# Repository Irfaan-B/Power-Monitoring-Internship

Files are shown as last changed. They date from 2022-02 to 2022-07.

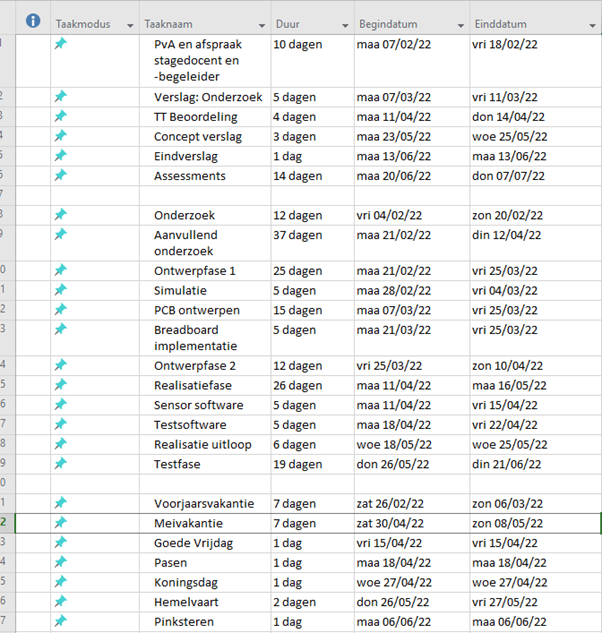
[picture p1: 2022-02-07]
Plan van Aanpak/Planning1.png

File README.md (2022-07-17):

# Three-Phase Power Monitor
A repository meant as version control for my internship at Crownstone.

## Plan of Action
The plan of action for this project can be found [here](https://github.com/IrfaanBodha/Power-Monitoring-Internship/blob/main/Research/Research.pdf)

A planning made for the second half of the project can be found [here](https://github.com/IrfaanBodha/Power-Monitoring-Internship/blob/main/Plan%20van%20Aanpak/Internship%20Planning%20(Second%20half).pdf)

## Report
Here you can find documents describing the research that has been done for this project:

- [Research on sensors](https://github.com/IrfaanBodha/Power-Monitoring-Internship/blob/main/Research/Research.pdf)
- [Test PCB for Rogowski coils and TMR sensors]
   - [Simulations](https://github.com/IrfaanBodha/Power-Monitoring-Internship/blob/main/Test%20Board/Simulations.pdf)
   - [Explanation of the schematic](https://github.com/IrfaanBodha/Power-Monitoring-Internship/blob/main/Test%20Board/Test%20board%20Explanation.pdf)
   - [Altium project files](https://github.com/IrfaanBodha/Power-Monitoring-Internship/tree/main/Test%20Board)

## The Product
This section will contain links leading to various files associated with the product that is being developed.

- [Internship Report](Report/Internship_Report.pdf)
- [Schematic](TPPM/TMRSensors.SchDoc)
- [Explanation of the schematic](TPPM/Circuit_Explanation.pdf)
- [PCB Files](TPPM)

## Sources
Sources will be listed in the [internship report](https://github.com/IrfaanBodha/Power-Monitoring-Internship/tree/main/Report).

## License
A file containing the license can be found [here](LICENSE.md)

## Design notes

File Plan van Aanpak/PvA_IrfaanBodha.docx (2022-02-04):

© 2022 Hogeschool Rotterdam

# Power Monitoring

# Plan van Aanpak

Opgesteld door | : | Irfaan Bodha
Stagiair | : | Irfaan Bodha
Begeleiders (Hogeschool Rotterdam) | : | John Roeloffs Robert Inpijn
Begeleider | : | A.C. van Rossum
Datum van uitgifte | : | xx-02-2022

Inhoudsopgave

Versiehistorie

Versie | Datum | Wijzingen | Auteur
0.1 | 03-02-22 | Eerste opzet | I.Bodha
0.11 | 04-02-22 | Risicoanalyse toegevoegd. | I Bodha

# 1. Achtergronden

Crownstone is een bedrijf dat gevestigd is in Rotterdam en is fabrikant van slimme stekkers en connectoren. Een Crownstone (kroonsteentje) product is een 16A schakelaar, LED-dimmer, vermogensmeter, soft-fuse, standby-killer en aanwezigheidssensor ineen. Het unieke kenmerk van dit product is de positiebepaling van smartphones en wearables, dit maakt het mogelijk om automatisch te reageren op aanwezigheid, binnenkomst en vertrek van specifieke personen.

Crownstone werkt aan het slimmer maken van huizen en kantoren. Crownstone gelooft dat huizen en kantoren nooit echt slim zullen worden als ze niet weten waar wij ons bevinden. Ook verwacht Crownstone dat in de toekomst positiebepaling binnenshuis groter zal zijn dan buitenshuis (GPS).

Op dit moment zijn crownstones producten die achter een stopcontact geïnstalleerd kunnen worden om het stopcontact slim te maken. Uiteindelijk wilt Crownstone de stopcontacten zelf slim maken en dus het huidige product integreren met stopcontacten. Slimme stopcontacten met functies als positiebepaling zullen uiteindelijk voor meer comfort, veiligheid en energiebesparing zorgen. Elektronica kan automatisch uitgeschakeld worden bij vertrek van personen wat niet alleen fijn is voor de gebruiker, maar ook energiezuinig. Ook is het veilig, omdat bepaalde elektronica die gevaarlijk zijn voor bijvoorbeeld kinderen, zoals een strijkijzer, automatisch uitgeschakeld zullen worden.

# 2. Projectresultaat

In dit hoofdstuk zal het projectresultaat besproken worden. Als eerst wordt de probleemstelling besproken, waar uitgelegd zal worden waarom dit project gedaan wordt. Vervolgens zal er worden besproken wat het doel van dit project is en welk elektrotechnisch systeem gerealiseerd zal worden in dit project.

## Probleemstelling

Crownstone wilt een product voor het meten van hoge vermogens en 3 fasen, waarbij er geen aanpassing aan de installatie nodig is. Dit is belangrijk voor bijvoorbeeld liften en apparaten in ziekenhuizen, waar het onacceptabel is om bijvoorbeeld een kabel door te knippen om zo individueel te stromen te meten door elke fase.

Op dit moment bestaan er stroomtangen die door middel van het meten van het magnetisch veld de stroom kunnen bepalen dat door een single core draad loopt. Dit is echter niet mogelijk in 3-fasen draden, omdat de netto stroom dat gemeten zal worden 0 zal zijn.

Door middel van het nauwkeurig plaatsen van sensoren zal het echter wel mogelijk zijn om met het nieuw product de stroom door de 3 fasen te meten zonder de kabel door te knippen. Met behulp van magnetische sensoren zal het bijvoorbeeld ook mogelijk zijn om meer te meten dan alleen vermogen, bijvoorbeeld het wegvallen van een fase of de aanwezigheid van triplen harmonics.

## Doelstelling

Het doel van dit project is om uiteindelijk een product te ontwerpen en realiseren dat de vermogen kan meten van een 3-fasen draad zonder dat het apparaat in-line wordt aangesloten. Dit zal gedaan worden met behulp van magnetische sensoren.

Er zal een PCB ontworpen worden die de bovengenoemde sensoren zal bevatten. Ook zal de PCB een microcontroller bevatten, de nRF52832 of de nRF52840. Dit zal nodig zijn om de data van de sensoren uit te kunnen lezen en verwerken.

Tijdens dit project zal er ook software geschreven worden voor de microcontroller. De software zal de data van de sensoren uitlezen en er zal ook testsoftware geschreven worden om de PCB te kunnen testen.

# 3. Projectactiviteiten

Om dit systeem uiteindelijk te kunnen realiseren zullen er specifieke activiteiten plaats moeten vinden. De student zal beginnen met het opstellen van dit plan van aanpak. Vervolgens zal er een analyse uitgevoerd moeten worden om zo de technische en niet-technische eisen te bepalen. De eisen zullen besproken worden met de begeleider.

Vervolgens zal er een onderzoek gehouden worden. Het doel van dit onderzoek is het bestuderen van benodigde theorie die relevant is voor de opdracht, zoals magnetische velden en 3-fasen theorie. Ook zal er tijdens de onderzoek gezocht worden naar geschikte type sensoren.

Het product zal uiteindelijk ontworpen worden in Altium. In dit programma zal dus de PCB ontworpen worden. Ook zal er een PCB gerealiseerd worden.

De schakeling zal ook opgebouwd worden op een breadboard om zo het ontwerp te testen.

Er zal software geschreven worden om de sensoren uit te kunnen lezen, en software om de PCB te testen.

Na het fabriceren van de prototype PCB zal er feedback ontvangen en verwerkt worden, en zullen gemaakte fouten verbeterd worden voor een volgende iteratie. Ook zal de BOM (bill of materials) geoptimaliseerd worden.

# 4. Projectgrenzen

Binnen de scope van deze opdracht valt het schrijven van software om sensoren uit te lezen en testsoftware voor de PCB. Er zal geen software geschreven worden voor het verwerken van de data.

Als er genoeg tijd is zal er ook een ‘pro’ versie van het product ontwikkeld worden. Deze versie zal nauwkeuriger zijn en zal geschikt zijn voor lagere minimum input en hogere maximum input waarden. Deze versie is geen vereiste, maar er zal wel geprobeerd worden om deze versie te realiseren.

De deadline van het verslag voor dit project is 13 juni 2022. Als er eventueel een herkansing nodig is zal het project langer duren.

Een aantal randvoorwaarden om dit project goed af te kunnen ronden zijn:

- Begeleiders moeten beschikbaar zijn voor het leveren van feedback en beantwoorden van vragen.
- De student moet toegang hebben tot een communicatiemiddel om communicatie tussen de student en collega’s mogelijk te maken wanneer er thuis gewerkt wordt, in dit geval een Discord server.
- De student moet toegang krijgen tot een Altium licentie, aangezien het gebruiken van dit programma verplicht is tijdens dit project.
- De student moet toegang krijgen tot faciliteiten om het ontwerp en gerealiseerde PCB’s te kunnen testen.

# 5. Tussenresultaten

- Programma van Eisen
- Het hoofdstuk ‘Onderzoek’
- Een tussentijdse beoordeling van de bedrijfsbegeleider
- Een concept verslag
- Het eindverslag
- Een prototype van het product gebouwd op een breadboard
- Een prototype PCB van het product
- Revisies van de PCB met verwerkte feedback en verbeteringen
- Software om data van sensoren mee uit te lezen
- Testsoftware voor de PCB

# 6. Kwaliteit

Om er zeker van te zijn dat de kwaliteit van dit project voldoet aan de eisen van de opdrachtgever zullen er requirements opgesteld worden. Door het eindproduct met de requirements te vergelijken en te testen zal er zo bepaald worden of de kwaliteit van het product voldoet.

De student zal aan het einde van elke week een email sturen naar de bedrijfsbegeleider om de voortgang toe te lichten. Ook is dit een moment om vragen te stellen en eventuele knelpunten toe te lichten. De student zal ook feedback ontvangen op het ontwerp, de documentatie en het stageverslag. Deze feedback zal dan verwerkt worden waardoor het eindproduct en eindverslag aan de opgestelde eisen zal voldoen.

Voor versiebeheer zal er gebruik worden gemaakt van een publieke Git repository. Met behulp van Git zullen de documenten altijd online beschikbaar zijn voor de begeleiders. Hier (https://github.com/IrfaanBodha/Power-Monitoring-Internship) is een link naar de repository. Als er eventueel documenten zijn die liever privé bewaard worden dan zal er gebruik gemaakt worden van Google Drive.

Voor het ontwerpen van de PCB zal er gebruik gemaakt worden van Altium. Er zal gecommuniceerd worden via Discord. Tot slot zal tekst geschreven worden in LaTeX, op de website van Overleaf.

# 7. Projectorganisatie

Naam | Functie | E-mail
Irfaan Bodha | Stagiair | 0882953@hr.nl irfaan.bodha@gmail.com
Anne van Rossum | Bedrijfsbegeleider | anne@crownstone.rocks
John Roeloffs | Begeleider | j.w.roeloffs@hr.nl
Robert Inpijn | Begeleider | inprm@hr.nl

# 8. Planning

Hier is een overzicht van de planning.

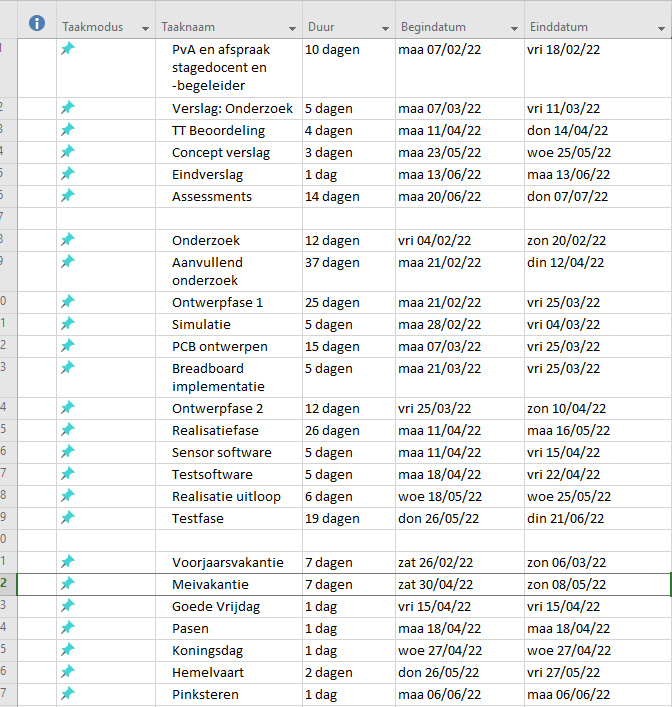
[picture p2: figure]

Voor een strokenplanning zie bijlage [1].

# 9. Kosten en baten

Het totale budget voor het product zal tussen de 300 en 400 euro liggen. Het exacte bedrag is nog niet bekend.

Er zullen 840 uur gespendeerd worden aan het project, waarvan 80 uur aan het stageverslag gewerkt zal worden.

Uiteindelijk zal Crownstone dankzij dit project hun productlijn rondom power monitoring verder uit kunnen breiden. Omdat de bestaande installaties waar de stroom gemeten zal worden niet aangepast hoeven te worden zal dit product zeer handig zijn voor toepassingen waar het aanpassen van de installatie onacceptabel is. Denk hierbij aan bijvoorbeeld het monitoren van een lift of apparaten in een ziekenhuis.

De student zal met behulp van dit project zijn competenties kunnen ontwikkelen en professionele werkervaring opdoen.

# 10. Risico's

Wat kan de voortgang van het project in gevaar brengen?

In dit hoofdstuk zullen de risico’s besproken worden die mogelijk invloed kunnen hebben op het project. Via een risicoanalyse zullen de grootte van de risico’s en mogelijke oplossingen bekend worden.

Een risico is opgebouwd uit de kans van optreden van de gebeurtenis en het gevolg die de gebeurtenis heeft. Kans en Gevolg zullen getallen zijn van 1 tot en met 10, en het risico zal uiteindelijk een vermenigvuldiging zijn van die twee getallen.

Grootte risico = Kans * Gevolg

Risico’s | Kans | Gevolg | Risico | Maatregelen
Onjuiste planning | 3 | 8 | 24 | Preventief: Planning zal gecontroleerd worden door begeleiders, en feedback zal toegepast worden.
Planning is te optimistisch | 5 | 8 | 40 | Preventief: Planning zal gecontroleerd worden door begeleiders, en feedback zal toegepast worden.
Planning wordt niet bijgehouden | 6 | 4 | 32 | Repressief: Zoveel mogelijk proberen om de planning bij te houden.
Te laat beginnen met een activiteit | 7 | 8 | 56 | Preventief: Planning goed bijhouden en zo goed mogelijk proberen te volgen.
Student heeft onvoldoende ervaring | 8 | 1 | 10 | Preventief: Door onderzoek te doen en vragen te stellen zal de benodigde ervaring verkregen worden.
Het project wordt tegengewerkt | 2 | 5 | 10 | Acceptatie.
Student wilt het product ‘te mooi’ maken | 3 | 7 | 21 | Repressief: Door het volgen van de planning zal er niet meer tijd besteed worden aan een onderdeel dan nodig is.
Te late levering van ingekocht materiaal | 8 | 10 | 80 | Preventief: Bestellen bij betrouwbare leveranciers en de levertijden goed controleren.
Vergeten van voorbereidingen | 1 | 10 | 10 | Preventief: Met het opstellen van een plan van aanpak zal de student goed voorbereid zijn.
Calamiteiten | 1 | 10 | 10 | Acceptatie.
Nieuwe overheidsregels | 8 | 8 | 64 | Acceptatie.
Projectopdracht is onduidelijk | 2 | 10 | 20 | Preventief: Door het opstellen van een duidelijk programma van eisen zal dit geen probleem zijn.
Opdracht wijzigt tijdens het project | 1 | 7 | 7 | Repressief: De opdracht en stageovereenkomst zijn geüpload op Praktijklink.
Hoeveelheid werk is moeilijk in te schatten | 6 | 8 | 48 | Preventief: Planning zal gecontroleerd worden door begeleiders, en feedback zal toegepast worden.
Doorlooptijd is onderschat | 1 | 8 | 8 | Preventief: De deadlines en overige data zijn vastgesteld in de planning.
Er is geen rekening gehouden met tegenvallers | 4 | 8 | 32 | Preventief: In de planning zal rekening gehouden worden met eventuele vertragingen.
Einddatum is niet realistisch | 3 | 10 | 30 | Preventief: De opdracht is goedgekeurd door de stagecommissie, dus het zou in principe mogelijk moeten zijn om op tijd af te ronden.
Prijswijzigingen van materialen | 8 | 5 | 40 | Repressief: In het geval dat de wijzigingen te extreem zijn zal er gekeken moeten worden naar andere leveranciers.
Beschikbaarheid producten | 8 | 8 | 64 | Repressief: In het geval dat de gekozen producten niet goed beschikbaar zijn, zal er gekeken moeten worden naar alternatieve leveranciers of producten.
Onbetrouwbare leveranciers | 2 | 8 | 16 | Preventief: Er zal alleen besteld worden van leveranciers waarvan het bekend is dat ze betrouwbaar zijn.
Ziekte | 10 | 7 | 70 | Acceptatie.
Familieproblemen | 5 | 10 | 50 | Acceptatie.
Slechte prestaties/motivatie/houding | 5 | 10 | 50 | Repressief: In het geval dat de student slecht presteert zal dit via meetings met begeleiders verholpen worden.

# Bijlagen

## Bijlage 1

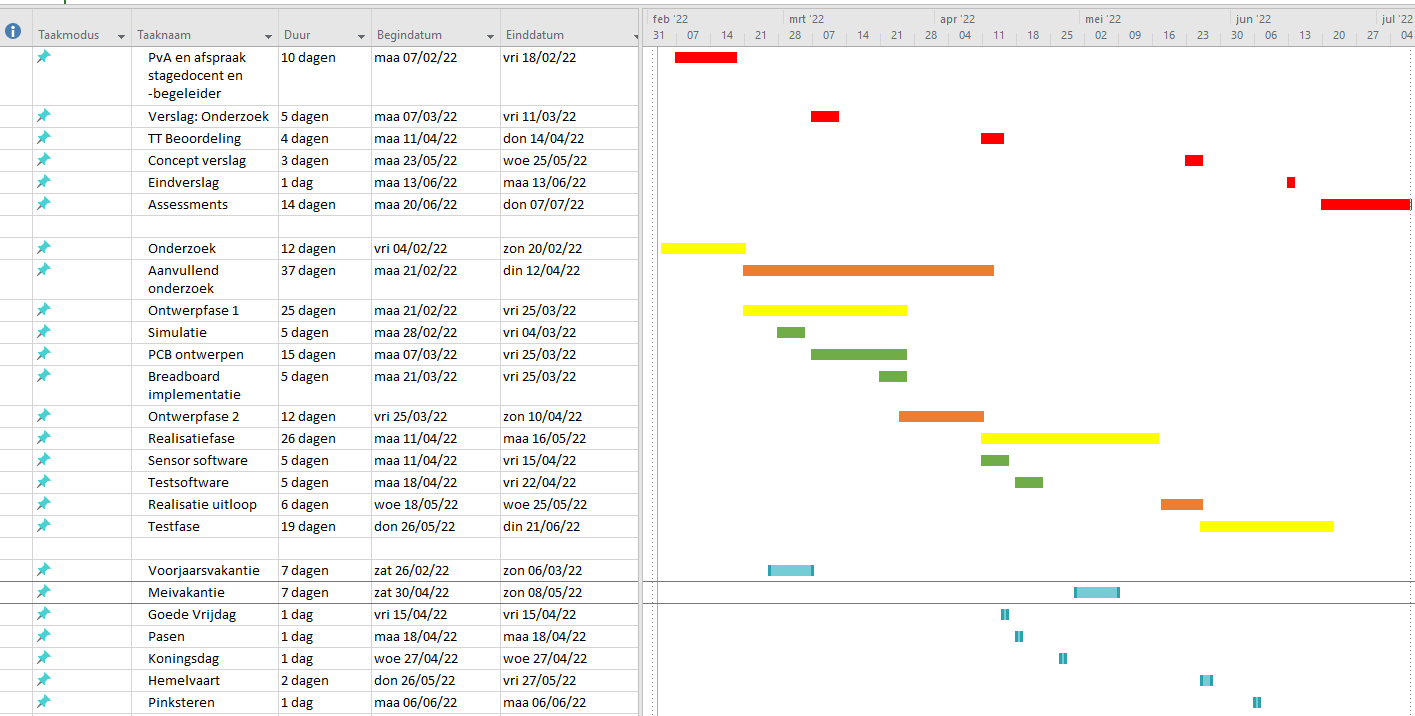
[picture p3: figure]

Versie 0.1Pagina 4 van 4

PvA Power MonitoringHogeschool Rotterdam

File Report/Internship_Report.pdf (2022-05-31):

# Three-Phase Power Monitoring

# Internship Report

## Intern: Irfaan Bodha Company Supervisor: Anne van Rossum Supervisor: John Roeloffs Supervisor: Robert Inpijn

Internship Report | Crownstone

## 1 Summary

This document will walk the reader through the design process of a Three-Phase Power Meter. The necessary research that has been done in order to design the product will be documented. Furthermore, this document shall feature information about the design and integration of the several units that together make up the power meter. A PCB shall be designed for this project, which will also be documented in this report, together with the various performed tests.

## Contents

1 Summary | 1
2 Three-Phase Power Monitor | 4
3 Research | 5
4 System Analysis | 15
5 Architecture | 20
6 Design | 25

7 Test Results | 36

## 2 Three-Phase Power Monitor

### 2.1 Introduction

### 2.1.1 Problem Definition

Crownstone is developing a product that can measure currents running through a three-phase cable in a non-intrusive manner. This will be useful for applications such as an elevator or in a hospital. Not having to interrupt the circuit in order to carry out a current measurement is crucial for these applications.

There are a number of non-intrusive current measurement devices on the market already, however these do not function well for a three-phase cable. The reason for this being the fact that with those devices, the user would be measuring the current on all three phases at once.

### 2.1.2 Aim of This Project

The aim of this project is to design and realise a product that is capable of measuring the current per phase in a three-phase installation in a non-intrusive manner. This device shall also feature the nRF52832 or nRF52840 micro controller, in order to output the data over Bluetooth.

At the end of the project, a PCB shall be designed and realised and the necessary software to read the sensors shall be written.

## 3 Research

This research document shall detail the research and experiments that shall be done in support of the three phase power monitoring project. In order to determine suitable requirements, experiments shall be done on magnetic sensors. The chosen sensors for these experiments are:
- Rogowski Coils
- Hall Effect Sensors
- Magnetoresistive Sensors

An amplifier circuit shall be designed and produced for the Rogowski coil. The procedures and calculations will be detailed in this report. To test the hall effect sensor, a hall effect module shall be connected to an Arduino Uno and the outputs will be read through a PC running an Arduino serial monitor. The magnetoresistive sensors will be mounted to a PCB and will also be read through a PC and Arduino software.

### 3.1 Rogowski Coils

### 3.1.1 Theory

Rogowski coils have been used for current measuring since 1912. [1] Traditionally, Rogowski coils have only been considered when other methods were unsuitable. Starting in 1965, the CEGB laboratories at Harrogate began investigating Rogowski coils for use in the power industry and developed the technology to produce high-accuracy and reliable measuring systems using Rogowski coils. [2]

Rogowski coils are toroidal windings placed around the conductor from which they will be measuring the current of. This way, the coil will pick up the electromagnetic field (EMF). The output of the winding is an EMF proportional to the rate of change of current. This is where the Rogowski coil differs from a current transformer, as a current transformer outputs the current that is being measured. The coils are designed to reject external magnetic fields, so that they may provide accurate measurements. The coil can be wound on a rigid former or it can be wound on a flexible former.

In order to monitor the current, the output of the Rogowski Coil has to be integrated. This is because the output of the coil is proportional to the rate of change of current. For this experiment, however, this shall not be necessary, since we are only interested in how sensitive a Rogowski coil is.

The output of a Rogowski coil is very low however, it can be as low as 40 microvolts per amp. [1] For this reason, an amplifier must be used in order to produce a reliable signal.

By choosing correct values for the amplifier, a single coil could theoretically be used to measure an extremely wide range of currents. The coil itself could also be wound more tightly, in order to increase the number of turns and therefore increasing its sensitivity.

One of the advantageous features of the Rogowski coil is that it is linear, because of this the coil could be used to measure a wide range of currents. Instead of having to change the coil when switching systems, the gain of the amplifier could be adjusted instead.

### 3.1.2 TL074 Amplifier

Two proposed circuits will be discussed in this section. The goal of the circuits shall be to amplify the output of the Rogowski coil so that it may be interpreted by a micro controller or observed through an oscilloscope. The output of the Rogowski coils are extremely low, that’s why the signal must be amplified. An op amp amplifier circuit shall be utilized for this. See figure 1 for a schematic of the amplifier using the TL074 op amp. The gain can be tuned by adjusting the value of R4. We can calculate the gain using this simple formula. 1.

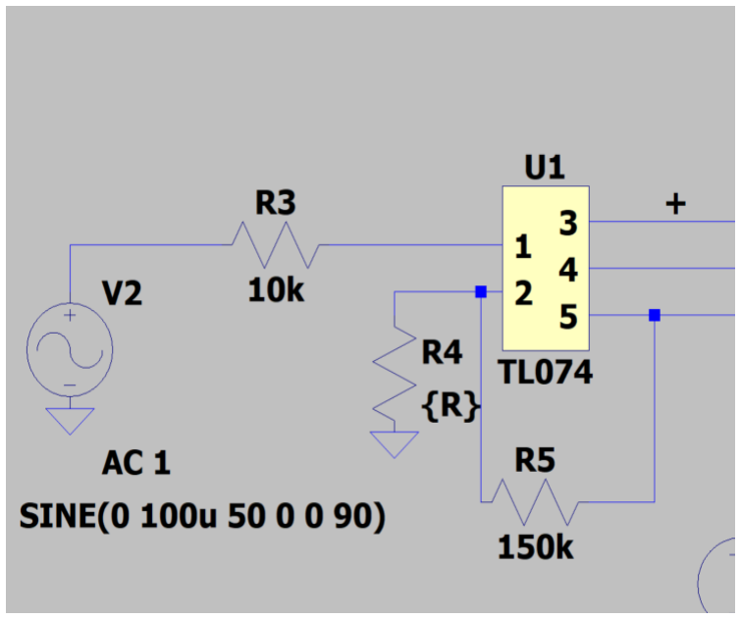
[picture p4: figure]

Figure 1: Amplifier using a TL074 op amp.

GAINnon−inv =

VOutmax − Voutmin

VInMax − VInM in

= 1 +

R5
R4

(1)

The output of a Rogowski Coil is not suitable for the input of an ADC. The ADC of an Arduino cannot read signals below -0.3V. Therefore, if we wish to observe the output through an Arduino, we will have to implement a level shifter circuit.

With a reference voltage of 2.5V, our signal will swing from that point rather than from 0V. This will prevent our signal from going below 0v, thus making it readable by an Arduino.

The gain for the level shifter can be calculated using formula 2.

GAIN =

R7
R9

∗

R9 + R8
R6 + R7
IfR9 = R6, then :

GAIN =

R7
R9

(2)

### 3.1.3 OPA2342

A circuit for the Rogowski coil using an OPA2342 shall now be discussed. This op amp features a few improvements over the TL074. Firstly, the op amp is a rail-to-rail amplifier. Unlike the TL074, input signals can swing all the way up to the level of the supply voltage. Secondly, a single supply voltage is sufficient to properly amplify the signal correctly. This makes a level shifter redundant as well, since the single (positive) supply voltage makes it so that the amplified signal stays in the positive range.

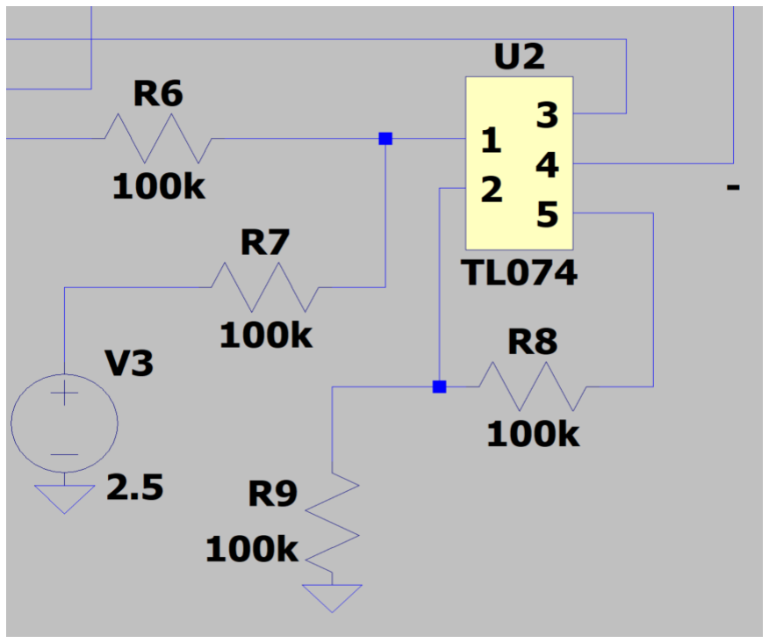
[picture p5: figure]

Figure 2: Level shifter using a TL074 op amp.

See figure 3 for the circuit. The gain for this amplifier can be calculated using the same formula as the gain formula for the TL074, formula 1, by plugging the values for R3 and R2 in R5 and R4 respectively.

In this section, the results of the simulations will be discussed. Multiple sweeps have been performed, including temperature sweeps, AC frequency sweeps and resistance sweeps.

### 3.1.4 TL074 Simulations

The first simulation will be a resistance sweep on R4. This will be done to simulate a potentiometer, so that the gain may be adjusted on the fly. See figure 4 for the results. As expected, the higher the resistance goes the weaker the signal becomes because of the lowered gain.

Next, a temperature sweep shall be run to monitor the performance of the amplifier circuit through a certain range of temperatures. A sweep running from 0 degrees celsius to 100 degrees celsius has been selected. Notice how much the offset varies once the temperature starts to rise above 70 degrees celsius. See figure 5 for the results.

Lastly, an AC frequency sweep shall be performed. With this sweep we will simulate the frequency response of the circuit and we will be able to see the cut off frequency. See figure 6 for the results.

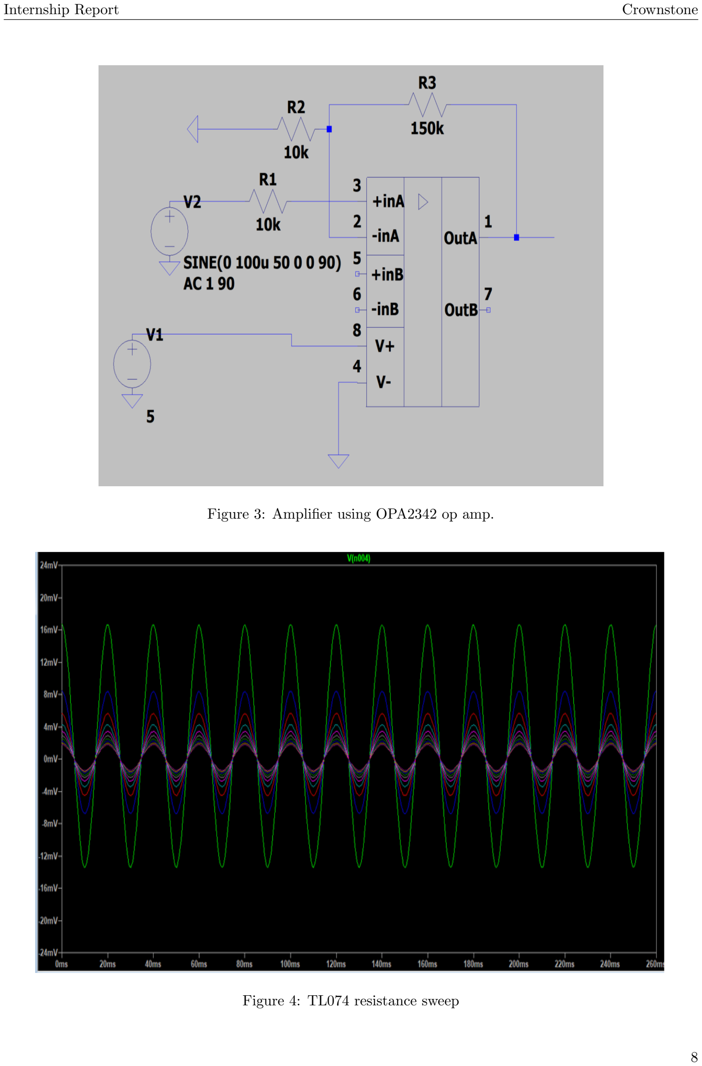
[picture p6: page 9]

Figure 3: Amplifier using OPA2342 op amp.

Figure 4: TL074 resistance sweep

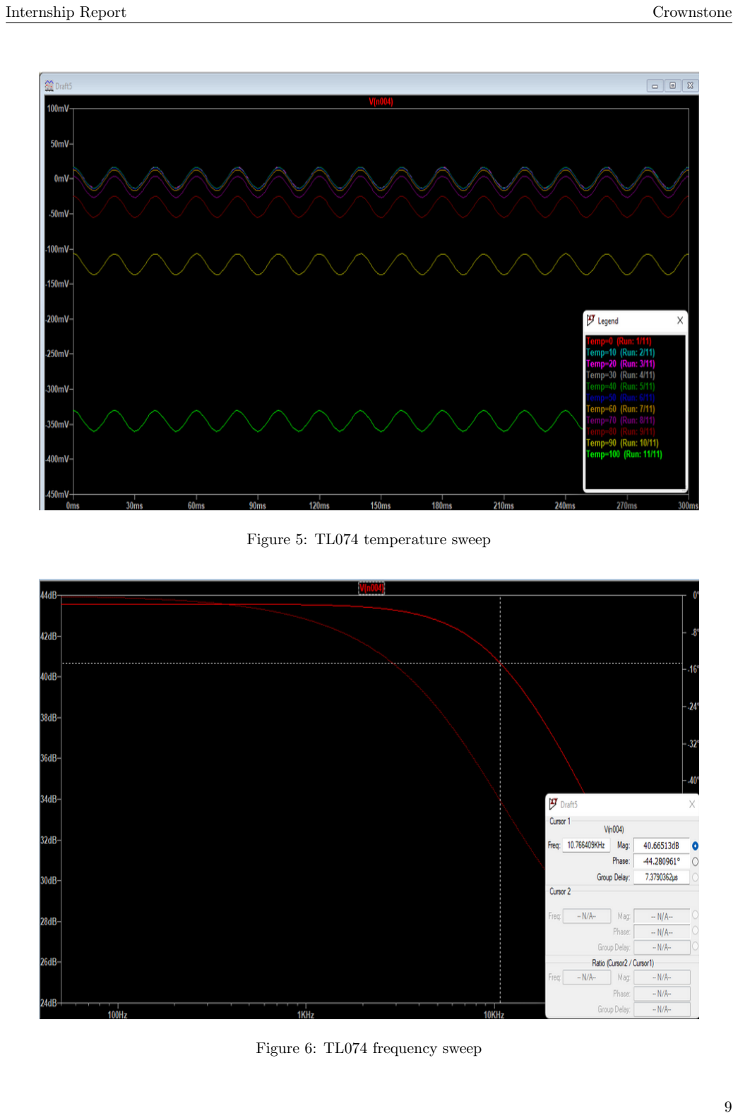
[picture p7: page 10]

Figure 5: TL074 temperature sweep

Figure 6: TL074 frequency sweep

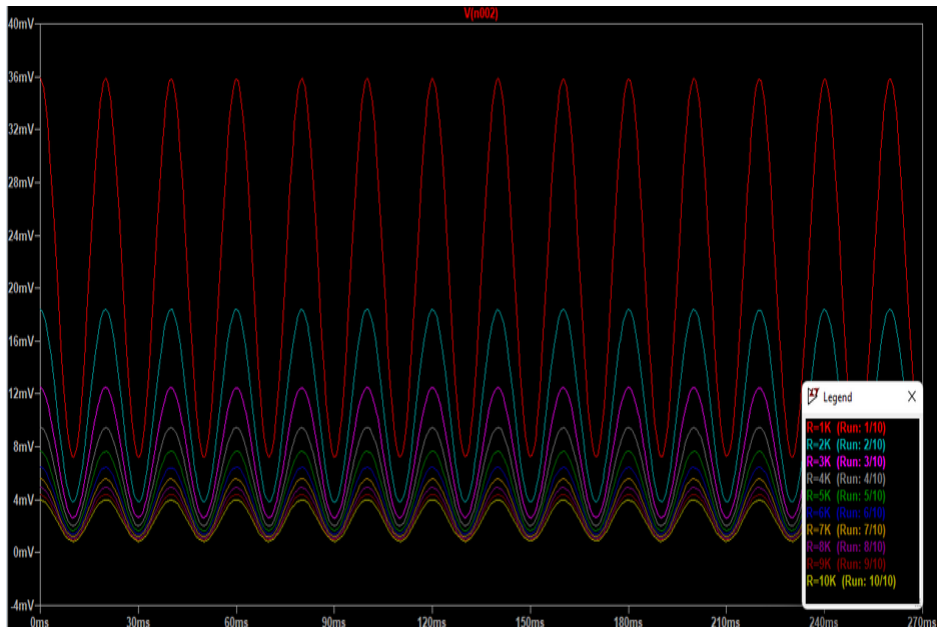
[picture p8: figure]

Figure 7: OPA2342 Resistance sweep.

### 3.1.5 OPA2342 Simulations

In this section we will discuss the simulations performed on the OPA2342 circuits. Just like with the TL074, multiple sweeps were performed to monitor the behaviour of the circuit based on temperature, frequency and resistance.

The first simulation will be the resistance sweep. Here, R2 (3) will be simulated with varying values, to simulate a potentiometer. See figure 7 for the results. Once again, the gain lowers as the resistance increases.

Next up is the temperature sweep. A temperature range of 0 degrees Celsius up to 100 degrees Celsius has been selected. See figure 8 for the results. Note how temperature affects this circuit much less than the TL074 circuit. In fact, it appears that temperature barely affects the circuit at all.

Finally, we have the frequency sweep. The sweep ran from 50Hz up to 100KHz. We can see in figure 9 that the cut off frequency is at 10KHz.

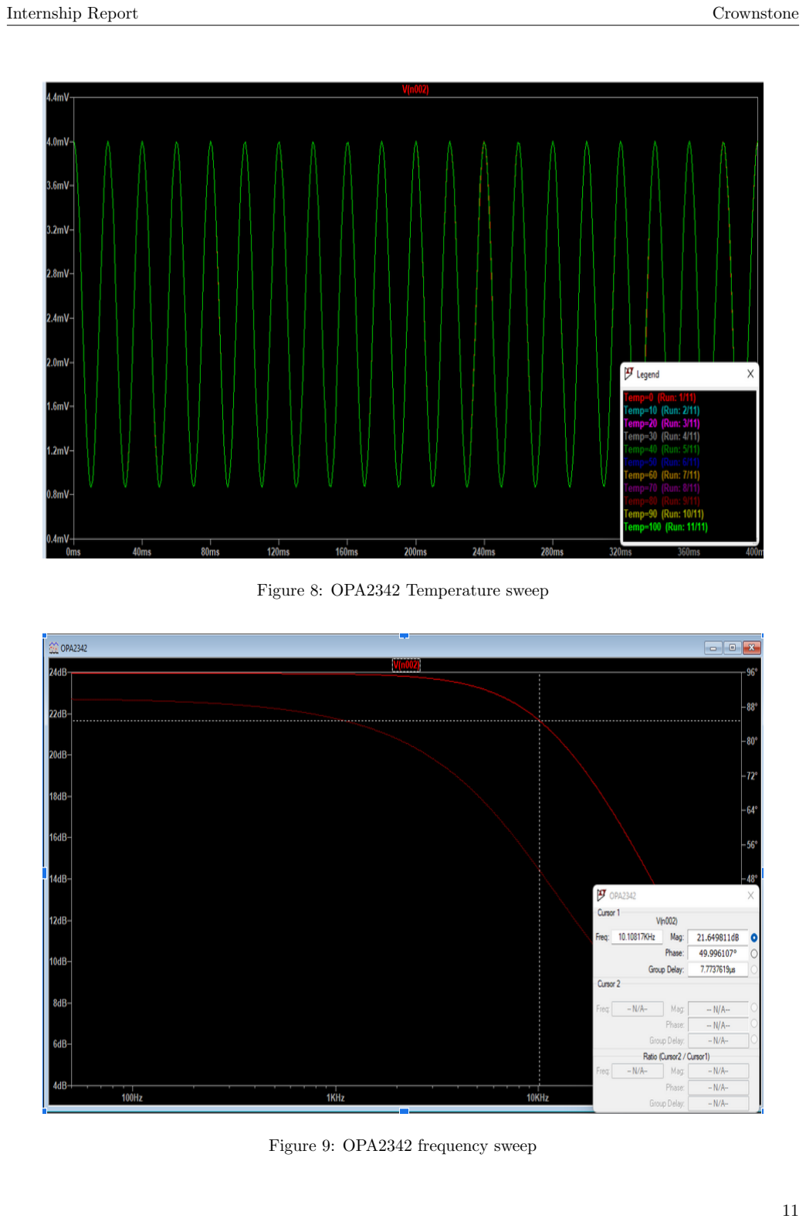
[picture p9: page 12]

Figure 8: OPA2342 Temperature sweep

Figure 9: OPA2342 frequency sweep

### 3.2 Hall Effect Sensors

### 3.2.1 Theory

The hall effect sensor is named after American physicist Edwin Hall. Hall discovered that objects can be moved by electricity and magnetism. Hall effect sensors used that principle to convert magnetically encoded information into electrical signals.

Hall effect sensors have a vast range of applications, including several uses in the automotive industry such as position sensing, speed and distance sensing etc.

When a current flows through any material, the electrons in the current move in a straight line. The electricity creates its own magnetic field. If this electrically charged material is placed between the poles of a permanent magnet, the electrons will move with a curved path instead. This is because their own magnetic fields react to the magnet’s magnetic field. As a result of this, more electrons will be present at one side of the material than the other. Because of this a potential difference, voltage, appears across the material. [3]

Hall effect sensors will measure the changing voltage across this material. With this method, the sensor can detect that is in a magnetic field.

Hall effect sensors are activated by an external magnetic field. The two most important characteristics of a magnetic field are flux density (B) and polarity (north and south).

The output of a Hall effect sensor is the function of the magnetic field density around the sensor. When the external magnetic flux density around the sensor exceeds a certain threshold, the sensor will output a voltage called the Hall voltage, Vh.[4]

Hall effect sensors are usually utilized to detect proximity, position or speed of mechanical targets. They can, however, also be used as current sensors. The way this is achieved is by measuring the magnetic field that is generated by the current.

In theory, to create a current sensor a hall effect sensor could be placed close to a conductor that is carrying a current. The sensor has to be placed in such a way that the magnetic flux lines can be detected, see figure [x].

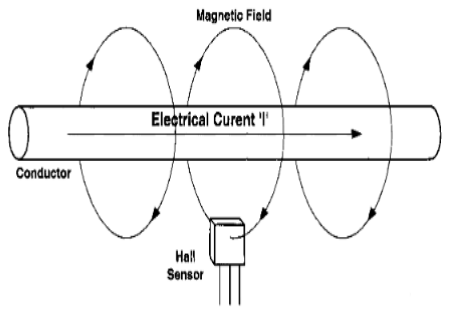
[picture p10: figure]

Assuming that there is only empty space surrounding the conductor and the conductor has a circular cross-section, the magnitude of the magnetic field can be calculated by the following equation:

B =

µ0I
2πr

(3)

R in this equation is the distance to the center of the conductor in meters.

While this would be an ideal setup, in reality this introduces several problems. Firstly, the generated magnetic field will not be substantial. For example, a 10 amp current will only generate about 2 Gauss at a distance of 1 cm.

4π ∗ 10⁻⁷ ∗ 10
2π ∗ 0.01
= 0.0002T or 2 Gauss | (4)

By this logic, the sensor will be influenced by external fields. One example of a field that could influence the
readings would be the magnetic field of Earth. Earth has a magnetic field of about 1 | 2Gauss. The generated
error would be 2.5 amps. From this we could draw the conclusion that in this configuration the hall effect sensor would only be suitable for measuring extremely large currents. If this would be applied for systems with less current, the measuring error would relatively be much higher.

2π ∗ 0.01 ∗ 0.00005
4π ∗ 10⁻⁷
= 2.5A | (5)

The second challenge would be the difficulty of correctly placing the sensor. To make the sensor effective, it is very important to place the hall effect sensor in the correct spot.

Thirdly, the calculations above assume an infinitely long and straight cable. In reality, however, cables are not infinitely long and there is a chance of the cable flexing and bending. The flexing and bending will have a major impact on the sensor’s sensitivity.

### 3.3 Magnetoresistive sensors

### 3.3.1 Theory

Magnetoresistive sensors (MR sensors) are linear magnetic field transducers. A MR sensor uses the fact that the electrical resistance in a thin magnetic film alloy is changed through an external magnetic field. Materials such as iron and nickel are commonly used for this alloy. MR sensors are very small and highly efficient, using very little current to operate. [5] An MR sensor can be used for multiple applications, such as:
- Angle measurement
- Magnetic field sensing
- Used as switches
- Current measurements

A simply way to explain the working of the sensors would be as follows: When the sensor comes into contact with a magnetic field, the electrical resistance changes. This also makes it possible to detect at what angle the external object is located. The magnetic field also makes it possible to determine the distance.

Technology has advanced to the point where researchers were able to create nanostructured multilayer devices with succesively larger giant magnetoresistance (GMR) and tunneling magnetoresistance (TMR) effects. Together with anisotropic magnetoreistance (AMR), these three types of sensors are currently in use.

A way to calculate the maximum obtainable signal from the sensor would be as follows:

MR% = Rmax − Rmin

Rmin

(6)

As mentioned earlier, the three types of MR sensors that will be discussed in this research are:
- AMR Sensors
- GMR Sensors
- TMR Sensors

### 3.3.2 Anisotropic magnetoresistance

AMR, or anisotropic magnetoresistance, sensors depend on the angle between the electric current and the magnetization direction. The AMR effect is a change in the paths of the electrons. The magnetic field distorts these paths. The change is maximum when the magnetic field is parallel to the sensor.

The resistance of the material of the sensor can be given by the following formula:

R = R0 + ∆R | (7)

## 4 System Analysis

Requirements will be set up and discussed with the stakeholder to insure the end product will be satisfactory. The requirements will also be used as a means to formulate various tests to test the functionality of the product.

Multiple illustrations shall be provided in this document to visualise the working of the product. With the help of a data context diagram (DCD) and a data flow diagram (DFD) the reader of this document will be able to get a clear picture of the inputs and outputs of the product, as well as the various subsystem and the connections between these subsystems.

### 4.1 Requirements

### 4.1.1 Functional Requirements:

REQ-1: The product will be able to measure current from a three-phase cable with up to 5 cores in a non-intrusive manner.
One of the most essential requirements of this project. The goal is to sense current from the aforementioned cable type without having to break the circuit. A possible scenario in which this product might be used is in a hospital. In this case, having to break the circuit to measure current would rather be avoided.

REQ-2: The product will be able to measure current from a cable while attached in a fixed position.
A must have for this product is the ability to sense current when the device is installed in a pre-determined location. Placing it in a random position, with the core positions unknown, is considerably more difficult and shall be treated as a ’nice to have’ feature.

REQ-3: The product will be able to measure current at a sample rate of 5KHz.
European AC voltage runs at a frequency of 50Hz. By sampling at a sample rate of 5KHz, 100 waveforms can be captured in a single second. With this data, the reactive power can be measured as well.

REQ-4: The product will be able to perform measurements on a 400V cable.
The standard phase voltage for Dutch three-phase cables is 400V.

REQ-5: The product will contain either a nRF52832 or nRF52840 micro controller.
These are the stakeholder’s and company’s requested micro controllers. Crownstone has already developed products using the nRF52832. Therefore, they have adopted the nRF chips into their ecosystem and have written a substantial amount of firmware for it.

REQ-6: The product will be able to output data over a USB connection.
Since the product will be powered over a USB connection, a USB data connection is also desired.

REQ-7: The product will be able to output data over a Bluetooth connection.
With a Bluetooth connection, the product will not be solely depending on a USB host device in order to output its data. This also makes the device more portable, as it won’t have to be tethered to, for example, a laptop or dekstop pc.

REQ-8: The product will be powered via USB.
In order to be perform measurements over a long period of time (i.e. for anomaly detection) it is much more reliable to have the device mainly powered by a non-battery solution.

REQ-10: The product should have a battery power supply.
If the product would feature a battery power supply as well, then it would make the product much more portable. Not only does it eliminate the need to be tethered to a USB device or charger, but because of the Bluetooth functionality the device can operate completely wirelessly.

REQ-11: The product could feature rechargeable batteries.
This would be a nice feature, it saves the user the frustration of having to switch out batteries and it’s a more economical and environmentally friendly approach than using disposable batteries.

REQ-12: The product could measure currents while attached to a cable in a random position. As mentioned earlier, it would be nice for the product to have this feature included. This, however, is a considerably more difficult requirement due to the fact that the distance between the sensors and the cores will have to be calculated.

### 4.1.2 Non-Functional Requirements:

NFREQ-1: The product could feature a 3D-printed enclosure.
The intern currently does not have any experience designing and 3D-printing enclosures. However, if there is time to spare at the end of the project, the intern would attempt to design and create an enclosure.

NFREQ-2: TBD: Cores and Shielding of the cables.

NFREQ-3: Lifespan of product.

NFREQ-4: The product should feature a redundancy of sensors, so it may continue to function in the event of a sensor failure.
It would be beneficial to feature a redundant amount of sensor, so that the entire device does not need to be replaced in the event a non-critical amount of sensors cease to function.

NFREQ-5: The device could have the ability to measure currents while being held by the user. Having someone hold the device while trying to measure current introduces constant tiny movements. Because of this, the distance to the cores needs to be calculated constantly.

NFREQ-6: The device should be completely level when two pcb’s are connected.
It is important for the device to be level when fitted around a cable. If it is not level, the angles from the sensors to the cable will not be constant, which would affect the calculations.

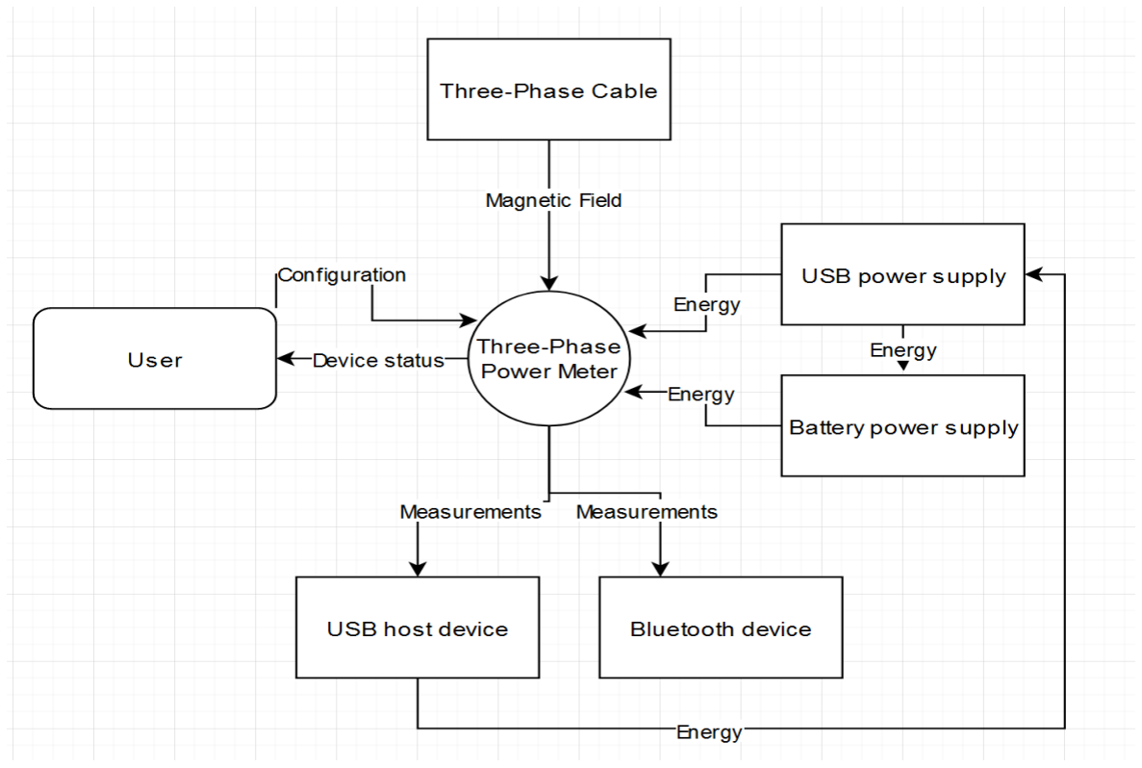
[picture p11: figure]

Figure 10: A Data Context Diagram of the system.

### 4.2 Data Context Diagram

A DCD has been drawn to illustrate the inputs and outputs of the device. The DCD can be seen in figure
10. The magnetic field gets picked up by the power meter and the device calculates the current running through the phases. This data will then be carried over USB or Bluetooth so that the user may read the data. The meter is powered by either a USB or battery power supply. In the event REQ-11 is implemented, this USB connection will also recharge the batteries.

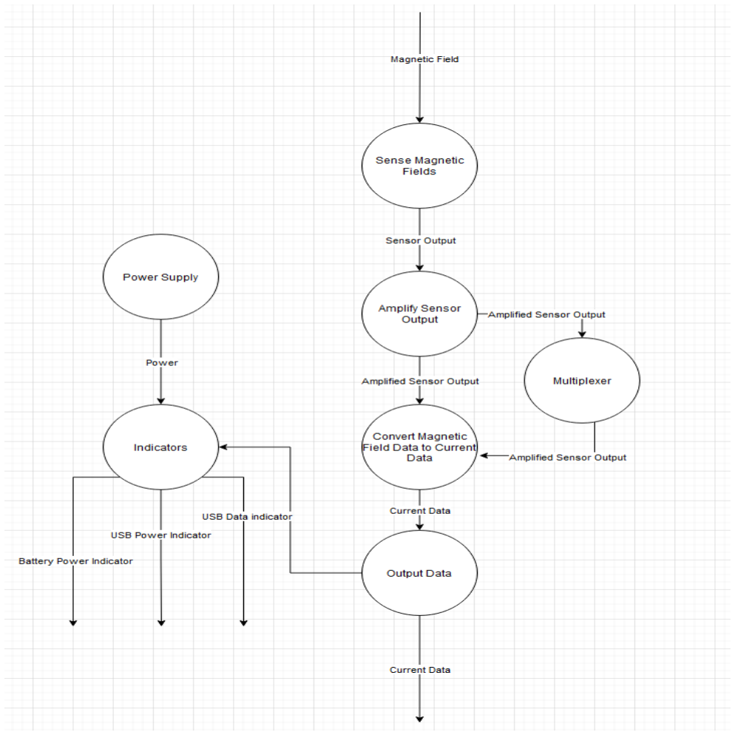
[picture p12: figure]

Figure 11: A Data Flow Diagram of the system.

### 4.3 Data Flow Diagram

A DFD has been drawn to illustrate the connections between the subsystems that comprise the system. This DFD can be seen in figure 11. The DFD illustrates the incoming magnetic field, after which it gets picked up by the sensors and proceeds to get amplified. This amplification is necessary since most magnetic field sensors have a very low output voltage-wise. After this step the designer has the choice to either send the data straight to the ADC of the micro controller, or send it through a multiplexer first. A multiplexer will allow the micro controller to receive data of a greater amount of sensors, since the micro controller has a limited amount of analog inputs. The micro controller will then convert this data to current data, which then will be sent over either USB or Bluetooth.

### 4.4 Acceptance Tests

Requirements | REQ-1, 2, 3, 4, 6, 8
Equipment | The three-phase power monitor USB host device (laptop) Three-phase cable
Test procedure | - Position the product around the three-phase cable. - Connect the product to the host device via USB. - Verify the connection between the product and the host device. - Verify if the product is measuring data. - Verify if the measured data matches the expected output.
Conditions | Test is considered successful if the product manages to measure current with an accuracy of +-10% and output the data over USB.

Table 1: Acceptance test 1.

Requirements | REQ-1, 2, 3, 4, 7, 8
Equipment | The three-phase power monitor Bluetooth device (phone) Three-phase cable USB power supply
Test procedure | - Position the product around the three-phase cable. - Connect the product to the host device via Bluetooth. - Verify the connection between the product and the host device. - Verify if the product is measuring data. - Verify if the measured data matches the expected output.
Conditions | Test is considered successful if the product manages to measure current with an accuracy of +-10% and output the data over Bluetooth.

Table 2: Acceptance test 2.

Requirements | NFREQ-4, 6
Equipment | The three-phase power monitor A level
Test procedure | - Visually inspect the product and notice the amount of sensors installed. - Connect two pcb’s together. - Use the level to verify if the pcb’s are level while connected to each other.
Conditions | Test is considered successful if the product features multiple redundant sensors and if it is level while two pcb’s are connected.

Table 3: Acceptance test 3.

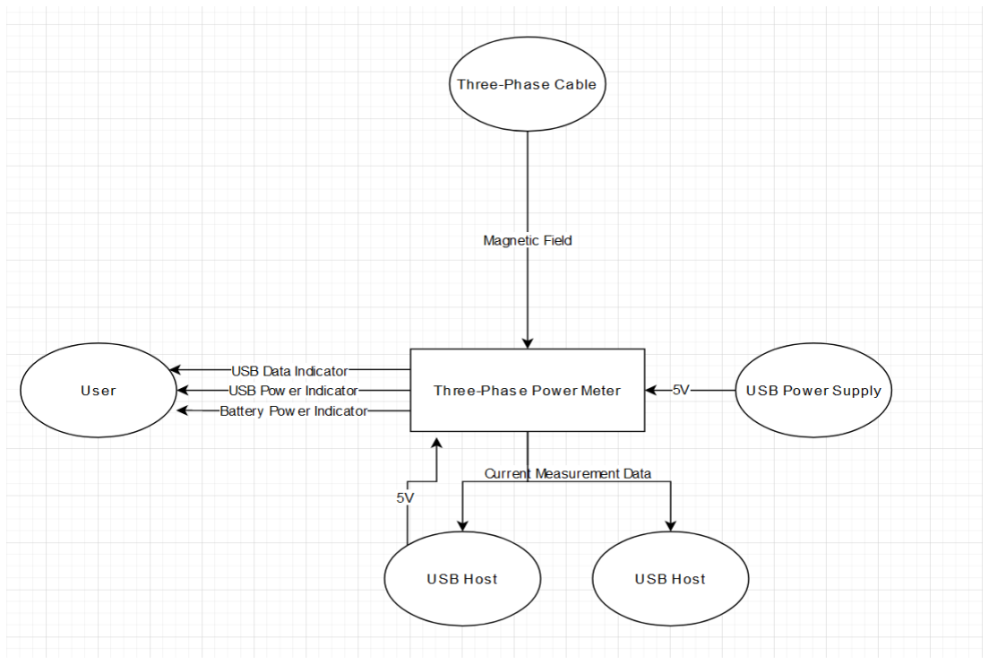
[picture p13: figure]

Figure 12: An ACD Describing the inputs and outputs of the system.

## 5 Architecture

This section will focus on the architecture phase. The connections to and from the device and various subsystems within the system will be highlighted. An Architecture Context Diagram has been drawn to illustrate the connections between and can be seen in figure 12. This section will also highlight the various design choices. These choices will be made for the following units:
- Magnetic Sensors
- Amplifier
- Micro Controller
- Multiplexer
- USB
- Board Connectors

### 5.1 Magnetic Sensors

For this unit it is essential that the sensor can detect a magnetic field from a suitable distance. This means the magnetic sensor has to be a contactless magnetic field sensor. The most ideal sensor for this would be a linear magnetic sensor, so that the current from a given magnetic field can be accurately calculated.

There are various ways to sense magnetic field. The methods that will be discussed now are:
- Rogowski Coils
- Hall effect Sensors

- Magnetoresistance Sensors

### 5.1.1 Rogowski Coils

Rogowski coils are usually the preferred current sensors due to their host of positive features. They feature no magnetic saturation, they cannot overheat and they suffer no losses due to hysteresis. They are also linear which means they can be utilized in many different systems with varying currents. At most, the amplifier and/or the amplifier’s gain will need to be adjusted to suit the output of the system.
Despite these positive features, a Rogowski coil would not be a suitable choice for the product, multiple coils would need to be deployed around the three-phase cable. This would drive up manufacturing costs and would completely eliminate the possibility of being able to find the location of the cores of the cable through measuring. Basically, the measurements would only be possible if the user knows the locations of the cores beforehand.

### 5.1.2 Hall effect Sensors

Hall effect sensors are used in applications such as proximity sensing, speed sensing etc. They can, however, also be used to measure current. Hall effect sensors are very sensitive to changes in distance and angle. Therefore, a magnetic flux concentrator is usually used for accurate measurements. This cannot be used for a three-phase current sensing solution, because putting a magnetic flux concentrator around an entire three-phase cable would result in a magnetic field of zero being read by the sensor.

### 5.1.3 Magnetoresistance Sensors

The last candidate for the product are magnetoresistance sensors. These sensors can measure a magnetic field using the principle of magnetoresistance. When applying a magnetic field to a resistor, its resistance changes and by applying a voltage across the resistors, the magnetic field can be measured. These sensors can also be used to measure the angle and the distance to the conductor. These sensors require no external components, like a magnetic flux concentrator, and are relatively small. This means that multiple sensors can be placed around a three-phase cable and can be used to both measure and locate the multiple cores.

### 5.1.4 Conclusion

Considering the positive and negative attributes of these types of sensors, the product shall feature Magnetoresistance sensors. These sensors will be able to measure the individual magnetic fields generated by the conductors accurately without disturbing the other magnetic fields. Multiple of these sensors will be able to be implemented in order to dynamically locate the conductors in a three-phase cable.

### 5.2 Amplifier

The output of the magnetic sensor needs to be amplified. This is because the outputs of these sensors typically range in the low millivolts. Therefore, amplifying these signals will make it possible to detect lower currents as well, also will it provide more accurate readings due to the analog to digital converter (ADC) of the micro controller.

Operational amplifiers (opamps) will be utilized in order to provide the necessary amplification for these output signals. The necessary gain and opamp configuration will be determined based on the selected sensor. Based on this data, a suitable opamp shall also be chosen later on in this document.

### 5.3 Micro controller

Crownstone has requested the use of either the nRF52832 or the nRF52840 micro controller. Crownstone has developed products with these Nordic chips in the past and thus are very familiar with them. They have written firmware for these chips in the past, firmware that will remain usable if newer products are developed using these chips.

It is essential for the product to feature bluetooth connectivity. For this product, a USB connection is also desired. the nRF chips feature both of these connections, therefore this request will not cause any conflicts with the design.

An ADC is also required, since magnetic sensors output an analog signal, this analog signal will need to be translated into a digital signal so that it maybe be output over bluetooth to a smartphone or other bluetooth enabled devices, or via usb.

### 5.4 Multiplexer

A multiplexer can be soldered on the PCB to ensure the micro controller can handle a large (more than 8) amount of sensors. This large amount of sensors is needed in order to detect the location of the conductors.

A multiplexer can take multiple inputs but only output one of them. This is done through an internal switching circuitry, and the signal can be selected through the use of a few selection pins, the amount of selection pins depends on the amount of possible in- and outputs.

Multiplexers with multiple outputs and different input configurations do exist, however they are not relevant for this product. For this product, multiplexers with multiple inputs and a single output will be used.

For a multiplexer it is crucial that it features a relatively low resistance, in order not to distort the signal too much and cause an inaccurate reading.

### 5.5 USB

This device shall be mainly USB-powered. Meaning, the input voltage shall be 5V and because it will utilize the USB 2.0 protocol, a maximum current of 500mA will be able to be drawn.

A USB connection is desired for this product. To act as the main power supply and to transmit data. A comparison between a few different connector types shall be made later in this document to determine which connector will be used.

### 5.6 Board Connectors

The device will be able to be clamped around a three-phase cable, this way, all the magnetic fields around the three-phase cable may be analyzed. In order for this to happen, there needs to be some sort of connection between the two halves. This prototype will not rely on an enclosure as a connection between two halves, it will instead use connectors on the pcb itself. These connectors will provide both a mechanical connection and an electrical connection between the two.

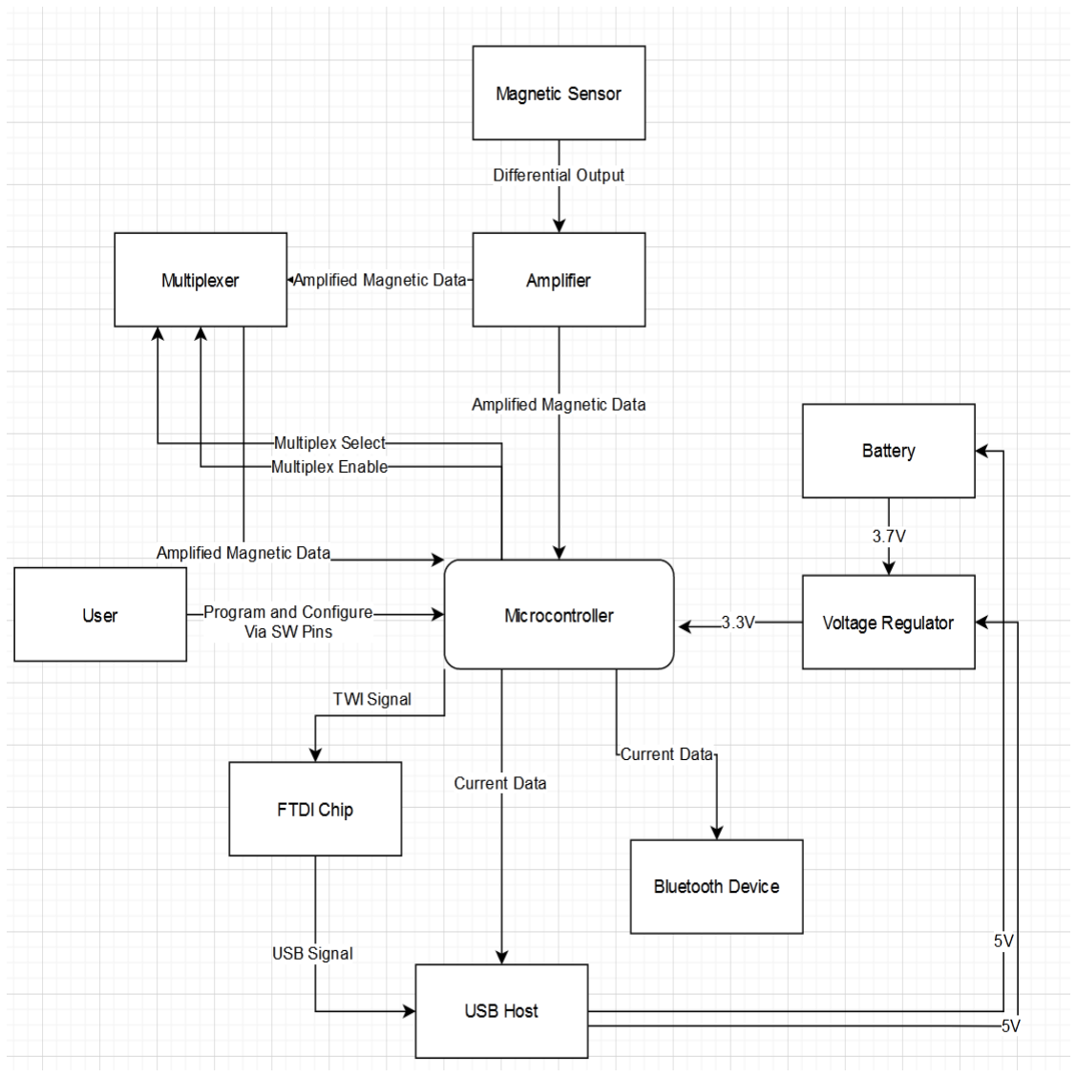
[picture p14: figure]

Figure 13: An AID showcasing the connections between units.

### 5.7 Architecture Interconnect Diagram

Now that the design choices have been made, an architecture interconnect diagram (AID) can be set up. This AID will help illustrate the connections between the units of this system. It also shows the type of connection these units share. The AID can be seen in figure 18.

### 5.8 Integration Tests

Units | Magnetic sensors & Amplifiers
Equipment | Oscilloscope Oscilloscope probes 5V power supply
Test procedure | - Turn the oscilloscope on - Connect the oscilloscope probes - Connect the product to a 5V power supply - Position the sensors near an alternating magnetic field - Probe the Sensor and corresponding Mux x testpoints - Verify that the signal is being amplified with a gain of 16 - Repeat this test for every sensor on the board
Conditions | Test is declared successful if all sensor outputs are being amplified with the correct gain of 16.
Units | USB & Magnetic sensors/ Amplifier/ Board connector/ Micro controller
Equipment | USB power supply
Test procedure | - Connect the board to a USB power supply - Use corresponding test points to determine if each unit is receiving power through the USB connection.
Conditions | Test is declared successful if every unit is receiving 5V +-10% from the USB connection.
Units | USB & Micro controller
Equipment | USB host device (laptop) The product
Test procedure | - Connect the board to a USB host device - Verify through the USB host device if the product is connected
Conditions | Test is declared successful if the micro controller is able to be detected by the USB host device.
Units | Board Connector & Magnetic sensors/ Amplifier
Equipment | 5V power supply Multimeter in volt mode
Test procedure | - Connect two pcb’s together via the edge connectors. - Connect the main pcb (the pcb with the nRF52840 module) to a 5V power supply. - Put the multimeter in volt mode - Use the multimeter to check the supply voltages of each unit.
Conditions | Test is declared successful if the multimeter reads 5V +-10% on every unit.

Unit | Component | Reason
Magnetic Sensor | CT100 | Continuous output Accurate differential output
Amplifier | OPA4342 | Rail-to-rail in- and output Low input offset
USB Connector | USB Type C | Future-proof Robust connector Better user experience
Micro Controller | IMM-NRF52840 Module | Module for ease of installation This module is relatively easy to implement compared to others No compromises
Board Connector | 2058703-1 | Suitable edge connector designed to connect multiple pcb’s Only one type of connector has to be ordered

## 6 Design

### 6.1 Component Selection

This section features a table filled with the chosen components for the design. These components shall be discussed further in the coming sections.

### 6.2 Magnetic Sensors

Suitable sensors have been found, the RR111 TMR sensor and the CT100 TMR sensor. Both of these sensors feature a linear output and can detect a magnetic field remotely. While the RR111 is cheap and arguably easier to implement, it has obtained the ’obsolete’ status, meaning no more new sensors of this type will be produced. The successor to this sensor, the RR112 TMR sensor, only has a maximum sample rate of 100Hz. This is far too low for this project, therefore the RR112 will not be utilized in this project. The CT100 on the other hand features a continuous output. The main difference with the output, however, is that the CT100 features a differential output. Meaning, the actual value of the magnetic field is the difference between the X2 and the X1 pins. See figure 15 for a schematic representation of this sensor. Since the difference between the two pins has to be calculated and amplified, since the output can be in the very low millivolts, a differential amplifier shall be utilized. The amplifier shall be discussed in the next section.

A simple RC high-pass filter will be implemented and both output pins of the sensor shall be connected to these filters. The filter features a cut-off frequency of:

F c =

1
2 ∗ π ∗ 150k ∗ 0.1u
= 10.6Hz | (8)

This filter is being implemented in order to filter out the DC component of the signals. Figure 14 for a functional block diagram of the sensor. The sensor features a voltage divider, in which the resistance of the resistors change based on the applied magnetic field. This means that there will always be a DC-voltage present on the outputs. Therefore, the outputs shall be connected to RC filters to filter out this DC-voltage.

Another reason the filters are being applied is to filter out the Earth’s magnetic field. The Earth has a constant magnetic field in the range of 25 to 65 µT. In order for this magnetic field to not interfere with the current readings, it shall be filtered out.

Conclusion: The CT100 will be used in this design. Its accuracy and sample rate capability make it worth the price.

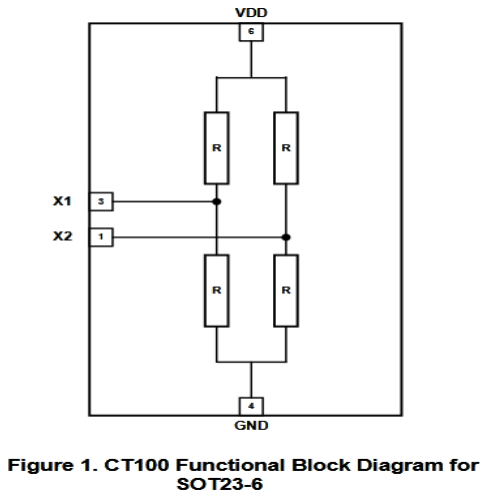
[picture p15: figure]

Figure 14: Block diagram of the ct100 sensor.

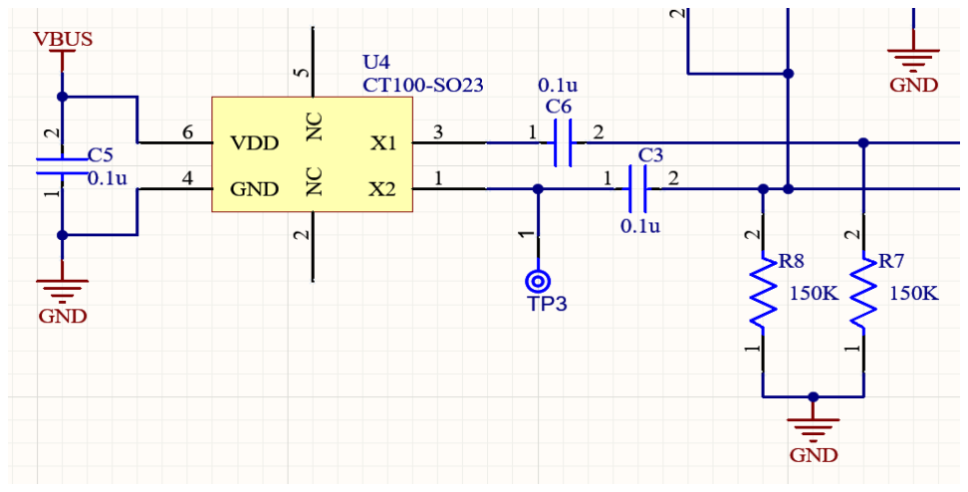
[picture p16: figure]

Figure 15: Schematic symbol and connections of the CT100 sensor.

Sensor | Pros | Cons
RR111 | Easy to implement Cheap | Obsolete
RR112 | Easy to implement Cheap | Sample rate is too low
CT100 | Accurate differential output Continuous output | Slightly more difficult to implement Slightly more expensive

Table 4: Design Considerations for the magnetic sensors.

### 6.3 Amplifier

A differential amplifier has to be utilized in this design. This is for the aforementioned magnetic sensors. For these amplifiers, it is important for them to be single-supply compatible. This is because the micro controller does not accept negative voltages on its analog inputs. Because the sensor’s outputs are in the millivolts range, feeding the amplifier with 5V will suffice. With a supply voltage this low, however, it would be desirable for the amplifier to be a so-called rail-to-rail output opamp. Meaning, the amplifier can amplify signals up to (or very near to) its supply voltage. An opamp with this particular feature, and low input offset has been selected: The OPA342 series. Figure 14 shows this opamp in the schematic and its connections.

In order for the micro controller to be able to measure negative currents as well, an offset shall be applied to the amplifier. A reference voltage will be applied to the non-inverting input of the opamp. This reference voltage shall be:

V ref = 5V ∗

1125K
2000K + 1125K
= 1.8V | (9)

This means, that if the micro controller reads a value below 1.8V, it shall be treated as a negative value. Vice versa, if the value is above 1.8V, then it shall be treated as a positive value. This all is necessary due to the micro controller not tolerating negative voltages below -0.3V

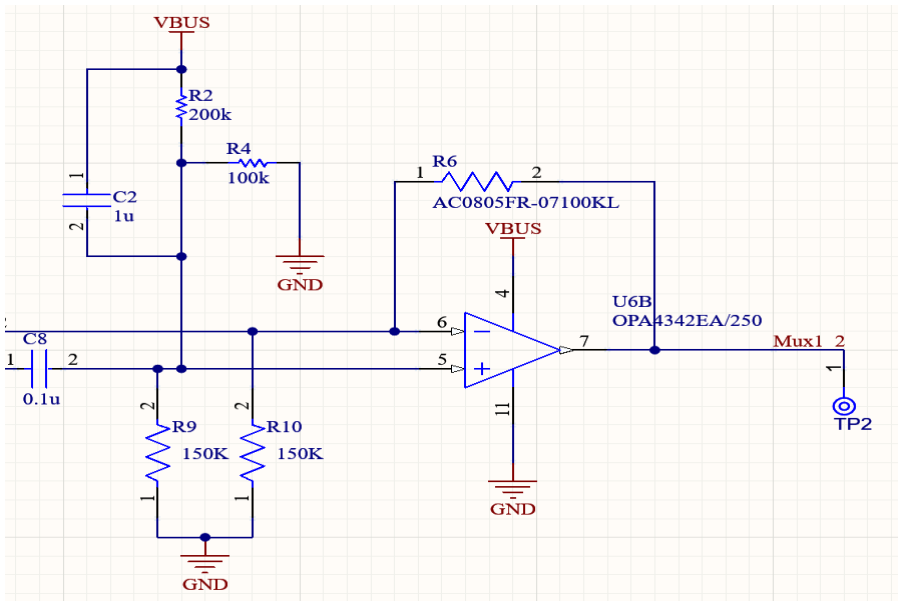
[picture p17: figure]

Figure 16: OPA4342 Amplifier in the schematic.

### 6.4 USB

In this section, a USB connector shall be chosen and then added to the complete circuit of the product. Considering the product will run the USB specification USB 2.0, many different connectors will be able to support the product. For this project, the comparison will be made between these three connectors:
- Mini-USB
- Micro-USB
- USB-C

In table 2, a quick comparison has been made with some pros and cons of each connector. For this product, the USB type C connector has been chosen. It is much more robust than the older generations of USB connectors. Most newer electronic devices that feature USB connectivity are implementing USB type C as well. Although it is slightly harder to implement compared to mini and micro, it is a necessary step in order to, ideally, only need one type of cable in the future. Therefore, picking USB type C can be seen as the most environmental friendly option. Because it can be plugged in both orientations, it is also seen as the most user friendly connector of the three.

The specific connector that has been picked is the USB4110-GF-A. This connector is relatively easy to hand-solder, compared to other USB type C connectors, as this connector features only one row of pins. Figure 17 shows the connector in the circuit.

R67 and R68 are connected to the configuration pins. If the host device detects a current through either of the 5.1k resistors, the host device can figure out the orientation of the cable and consequently turn on the correct VBUS line. F1 Is a fuse that has been added for protection, a maximum current of 500mA has been chosen as that is the maximum current draw of the USB 2.0 specification. C24 has been added for stability, and a ferrite bead has been added as well to filter out unwanted frequencies and provide cleaner power.

Connector | Pros | Cons
Mini-USB | Easy to implement Cheap | Fragile Outdated
Micro-USB | Easy to implement Cheap | Fragile On its way out
USB-C | Robust Better user experience Environmentally friendly compared to other options | Difficult to implement Slightly more expensive

Table 5: A table comparing three USB connectors.

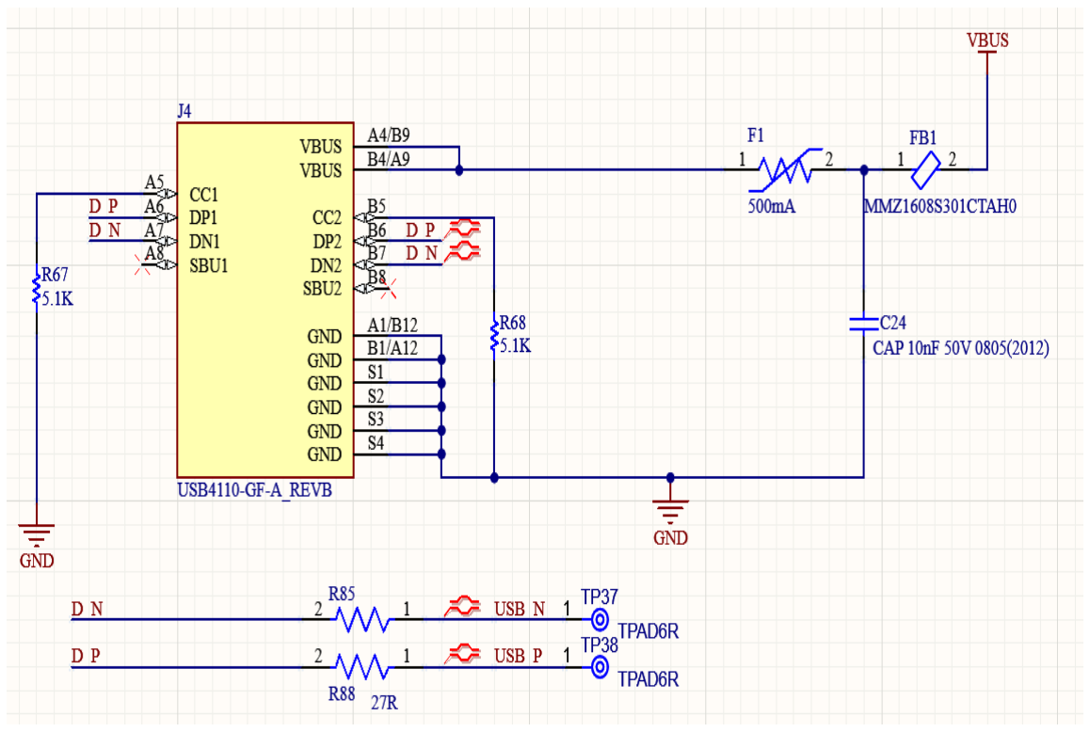
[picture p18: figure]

Figure 17: USB type C connector

### 6.5 Board Connectors

To connect multiple pcb’s together, the 2058703-1 has been chosen. This is a hermaphroditic connector specifically designed to connect multiple pcb’s together. In order to only need one nRF52840 module, these edge connectors will deliver power to the second pcb. The board will also feature three-pin JST connectors in order to share the magnetic sensor data. Figure 18 shows the power connectors in the circuit and figure 19 shows the data connector.

### 6.6 Micro Controller

The selected nRF52840 module is the IMM-NRF52840 made by i-syst. This module features all the desired functions for this product. It is also relatively easily to hand-solder when compared to similar modules on the market.

For programming and debugging, the product will feature a j-link connector. This is a 20-pin connector with 2x10 rows of header pins. The pins have been wired according to the diagram on the j-link device itself.

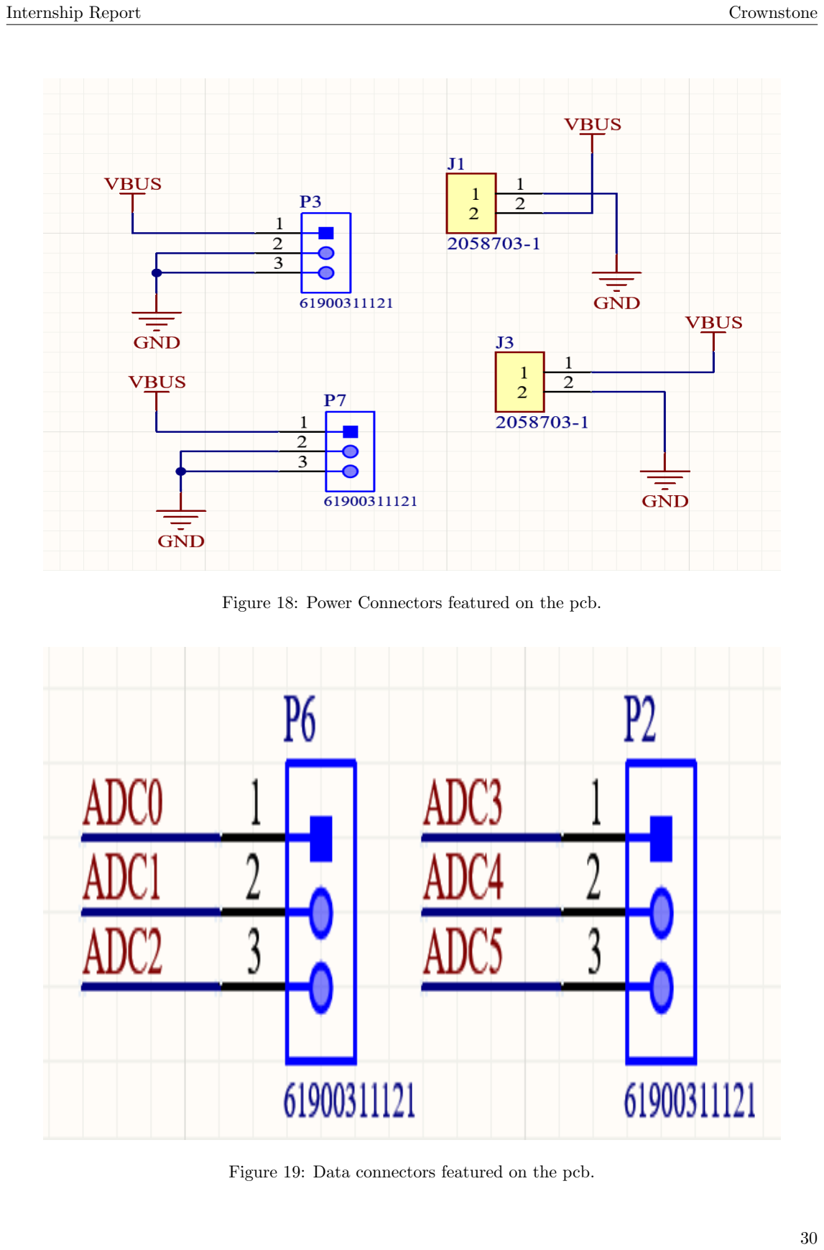
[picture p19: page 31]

Figure 18: Power Connectors featured on the pcb.

Figure 19: Data connectors featured on the pcb.

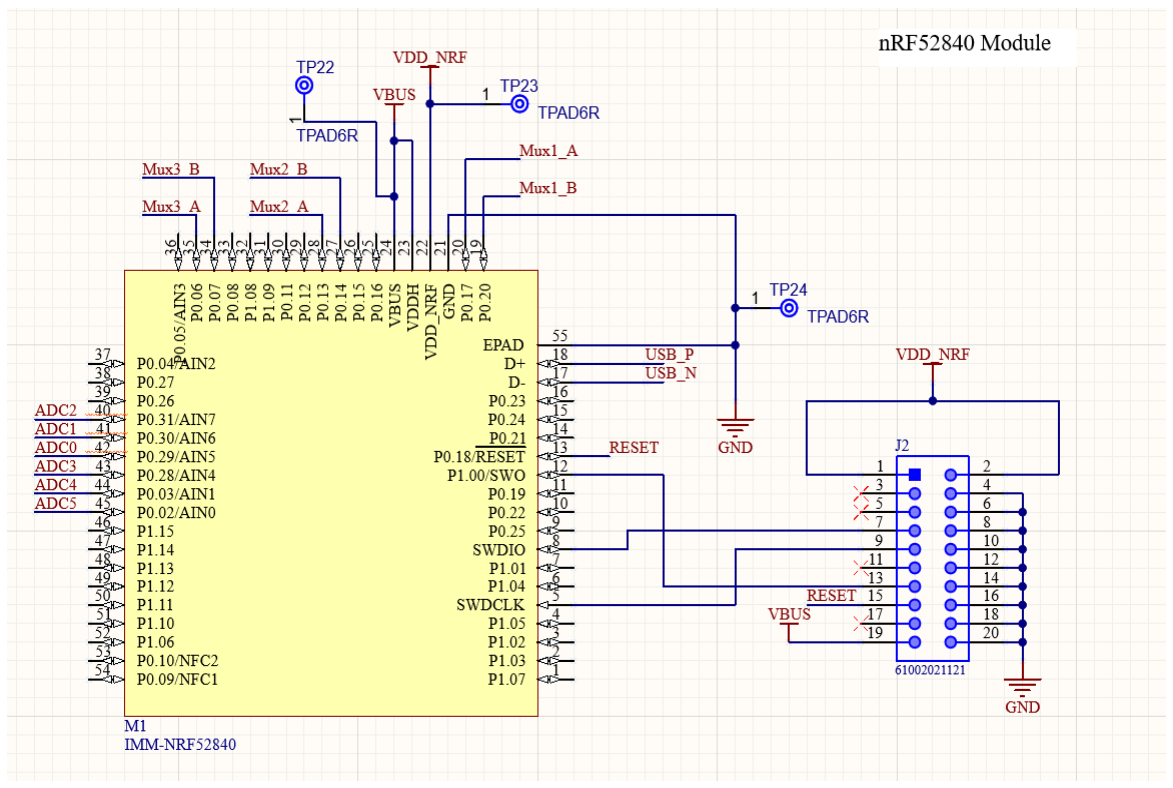
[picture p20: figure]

Figure 20: IMM-NRF52840 module in the schematic.

The module has been wired according to the schematic in figure 20. The outputs of the multiplexers have been wired to the AINx input pins of the nRF52840. The multiplexer signal selection pins have been wired to available GPIO pins.

### 6.7 Unit tests

Unit | Magnetic sensors
Equipment | Lab bench power supply set to 5V Multimeter in volt mode
Test procedure | - Turn on the lab bench power supply and set it to an output of +5V and limit it to 10mA. - Connect the lab bench power supply to the +5V and GND pins on the board. - Put the multimeter probes on the Sensor test point closest to the sensor and put the negative probe on a GND test point. - Confirm the DC voltage across the magnetic sensor. - Repeat this test for every magnetic sensor on the board.
Conditions | Test is declared successful if the multimeter reads 2.5V across every magnetic sensor, indicating that there is a DC voltage across
the internal voltage divider of the sensors. | 31

Unit | Magnetic sensor
Equipment | Lab bench power supply Oscilloscope Magnetic source
Test procedure | - Set the lab bench power supply to 5V and limit the current to 20mA. - Connect the power supply to the +5V and GND pins on the board. - Hold a probe to the Sensor test point near the sensor that is being tested. - Put the magnetic source near the sensor. - On the oscilloscope, verify that the sensor is indeed detecting a magnetic field. - Repeat this test for every sensor present on the board.
Conditions | Test is declared successful if every sensor on the board is able to detect a magnetic field.
Unit | Amplifier
Equipment | Lab bench power supply set to 5V Oscilloscope Magnetic source Function generator

Test procedure

- Turn on the lab bench power supply and set it to an output of +5V and limit it to 10mA.
- Connect the lab bench power supply to the +5V and GND pins on the board.
- Turn on the oscilloscope and connect the probes.
- Turn on the function generator and connect the probes.
- Put the function generator channel 1 on Sine wave mode, with a Vpp of 100mV and frequency of 50Hz.
- Put the function generator channel 2 on Sine wave mode, with a Vpp of 110mV and frequency of 50Hz.
- Connect the output of both function generator channels to the inputs of the amplifier. channel 1 to the non-inverting input and channel 2 to the inverting input.
- Connect the oscilloscope probe to the output of the amplifier and the ground clip to a GND pin on the board.
- Verify the output of the amplifier on the oscilloscope.
- Verify that the amplifier is correctly working as a differential amplifier and that the output is the difference of the two signals amplified by 16.
- Repeat this test for all the amplifiers present on the board.
Conditions | Test is declared successful if every amplifier correctly amplifies the difference of 10mV by 16, resulting in a signal with a Vpp of 160mV.

Unit | USB
Equipment | Multimeter Multimeter probes with thin tips USB power supply
Test procedure | - Ensure the multimeter is set to continuity mode. - Probe the USB type C connector pins with the corresponding test points (USB N and USB P) and listen for the audible beep. - Repeat this procedure for the VBUS pins and the GND pins. - Sweep the pins looking for possible shorts. - Connect the board to a USB power supply. - Switch the multimeter to volt mode. - Measure the voltage across the USB connector.
Conditions | Test is declared successful if: - There is continuity in the aforementioned pins and test points. - No shorts between the USB type C connector pins. - A voltage of +5V +-10% is present across the connector.
Unit | Board connector
Equipment | Lab bench power supplyMultimeter
Test procedure | - Set the lab bench power supply to 5V and limit the current to 20mA. - Put the multimeter in continuity mode - Probe the edge connectors (J1 and J3) and check for continuity on the +5V and GND pins. - Connect the lab bench power supply to the +5V and GND pins on the board. - Put the multimeter in volt mode and check the voltage across each connector.
Conditions | Test is declared successful if there is continuity on the 5V and GND connections and if a voltage of 5V is measured across both connectors.
Unit | Micro controller
Equipment | Multimeter Lab bench power supply
Test procedure | - Put the multimeter in continuity mode. - Using the test points located around the module on the board, check for continuity to ensure the module is soldered properly, these test points are: 1. NRF GND 2. USB N and USB P 3. NRF VBUS 4. VDD nRF - Set the lab bench power supply to +5V and limit the current to 50mA. - Using test points NRF VBUS and NRF GND, measure the voltage across the module.
Conditions | Test is declared successful if continuity is detected and if the voltage across the module reads +5V +-10%

Unit | Micro controller
Equipment | A desktop pc or laptop J-link programmer
Test procedure | - Connect the J-link device to the board and the pc or laptop. - Run nRF Connect on the computer. - Select an example code file for this test. - Upload example code to the nRF52840.
Conditions | Test is declared successful if the nRF52840 module is programmed successfully.

### 6.8 Schematic

Figure 21 shows the complete schematic.

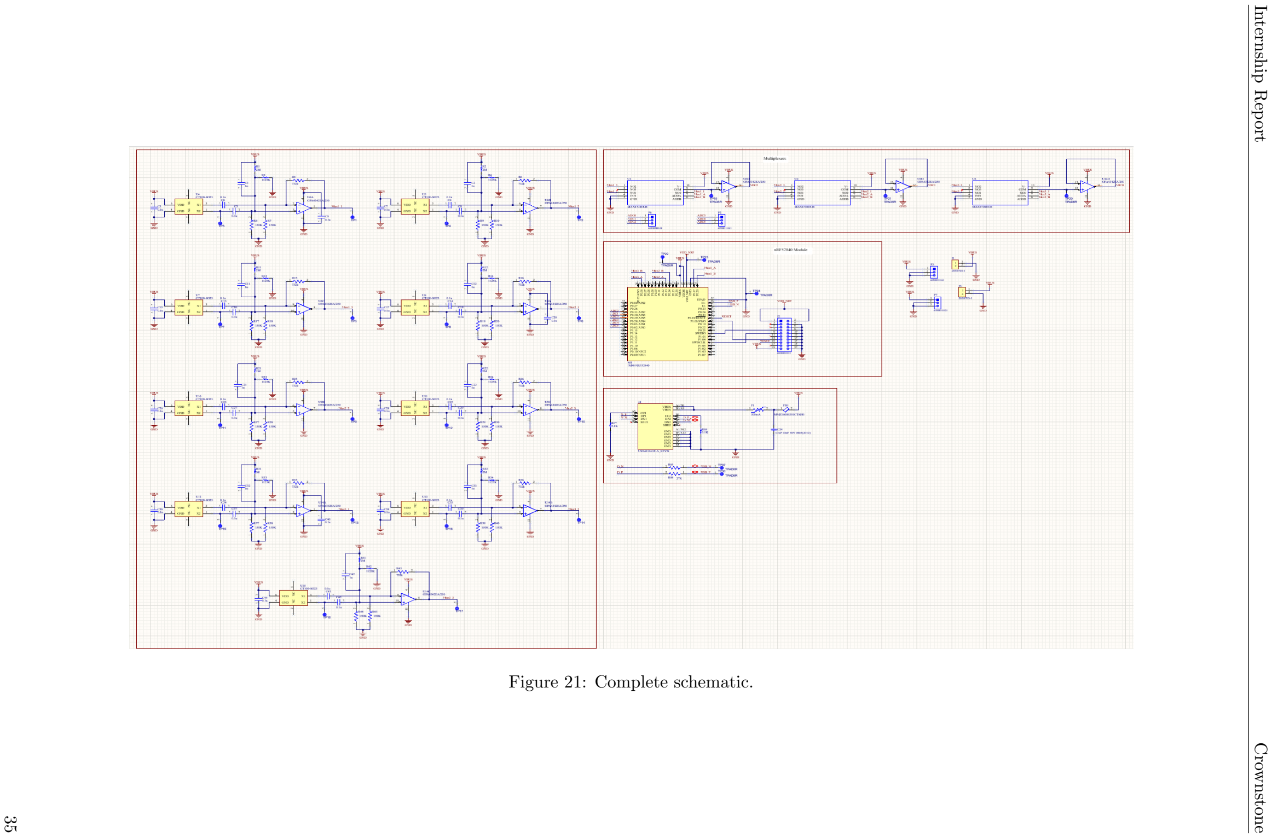
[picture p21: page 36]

Internship Report Crownstone Figure 21: Complete schematic.

35

### 6.9 PCB

Figure 22 shows the pcb that has been designed.

## 7 Test Results

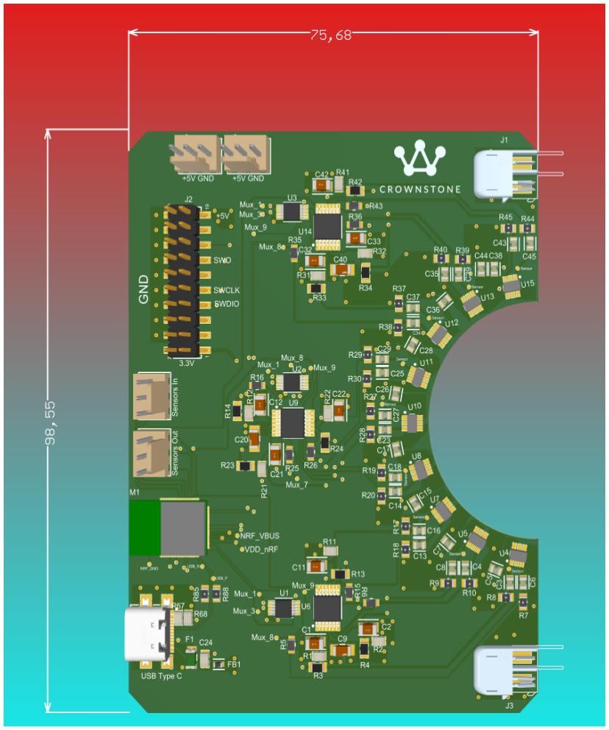
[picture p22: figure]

Figure 22: The PCB.

## References

[1] V. Fehlberg, “How rogowski coils work.”
[2] D. Ward, “Measurement of current using rogowski coils.”
[3] R. Ltd., “Everything you need to know about hall effect sensors.” [Online]. Available: https://ie.rs-online.com/web/generalDisplay.html?id=ideas-and-advice/hall-effect-sensors-guide
[4] E. tutorial, | “Hall effect sensor.” [Online]. Available: | https://www.electronics-tutorials.ws/
electromagnetism/hall-effect.html (https://www.electronics-tutorials.ws/electromagnetism/hall-effect.html)
[5] S. C. P P Freitas, R Ferreira and F. Cardoso, “Magnetoresistive sensors,” 2007.

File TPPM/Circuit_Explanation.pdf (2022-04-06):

# Three Phase Power Monitor

Irfaan Bodha

April 2022

## 1 Introduction

## 2 Circuit

The circuit will be discussed in this chapter. A PDF of the complete circuit can be found in the appendix.

### 2.1 Sensors

The sensors used for this project are the CT100 contactless TMR Field Sensors. These sensors are able to measure the magnetic field without coming in physical contact with the conductor[1]. This is crucial for this project, as the aim of the project is to develop a device that can sense current in a non-invasive manner. An alternative sensor that was considered for a short time is the RR111 TMR sensor developed by RedRock[2]. However, this sensor has become obsolete and is therefore not recommended for new designs. The replacement for the RR111, RR112, features a sampling rate of 100Hz. Considering that the product has a requirement to sample at a rate of 5000Hz, this new sensor is not suitable for this project.

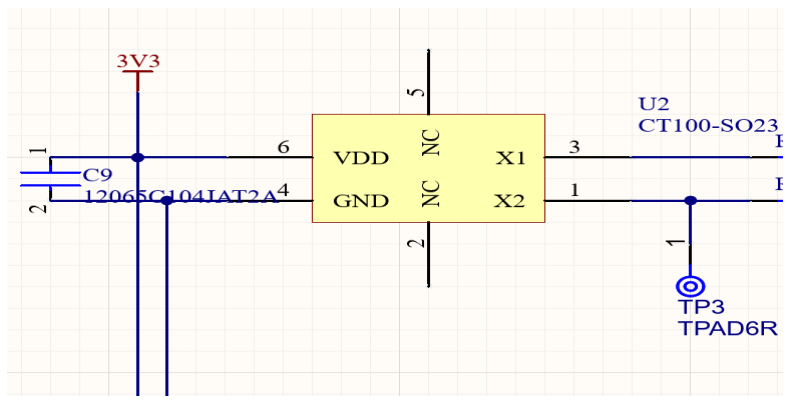
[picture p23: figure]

The CT100 features a differential output. The output of the sensor, the value of the magnetic field, is the difference between the X2 and X1 pins. As

1

the potential is measured between the two output pins and not from a single output pin to ground, less noise shall be present on the output.
The sensors also feature a 100nF decoupling capacitor across the supply pins, as per the recommended application mentioned in the datasheet.

### 2.1.1 Amplifiers

The output of the CT100 sensor shall be passed through a differential amplifier. The amplifier will calculate the difference between the two signals and shall then proceed to amplify the signal.
The op-amp (operational amplifier) that has been chosen for this project is the OPA342 series. This op-amp has been chosen for its rail-to-rail in- and output capabilities, it’s low input offset of ±1 mV and because of the power supply specifications. The op-amp can function with a (single) supply voltage of as low as 2.5V.
The amplifier circuit can be seen in this figure. The formula for calculating the gain can be seen in equation 1.

Ix1 =

Ux1−U−
R11

, Ix2 =

Ux2−U+
R13 , If =

U−−Uout
R7

U− = U+
U+ = Ux2 ∗

R17
R13+R17
IfUx2 = 0, thenUout(x1) = −Ux1 ∗
| R7 R11 (1)

### 2.1.2 Multiplexers

The output of the amplifier will be connected to either a multiplexer, directly to the analog input of the nRF52840 MCU. The connection depends on the amount of sensors present on the board. The connection and choice will be made using a 0 ohm resistor.
[Figure]
The multiplexer that has been selected for this project is the TMUX1208RSVR by Texas Instruments.
This multiplexer supports a supply voltage range of 1.08 to 5.5V. This means that we will be able to supply the multiplexer with 3.3V. With a supply current of only 10nA it’s also very efficient.
The multiplexer offers 8:1 single ended channels. Meaning, eight sensors will be connected to the multiplexer. The multiplexer will let one of those sensors through to the analog input pin at a time.
The multiplexers turn on by pulling the EN (enable) pin high. This pin features a 10k ohm pull-down resistor, per the recommendation found in the datasheet. Another recommendation from the datasheet is the 100nF decoupling capacitor on the VDD pin.

2

Pins S1 through S8 are used as inputs from the TMR sensors. The A0,A1 and A2 pins are used to select which input gets through the multiplexer. Pin D is the output of the multiplexer, which will be connected to the analog input of the nRF52840.

### 2.1.3 nRF52840 module

The nRF52840 module that will be used is the ACN52840 module by Aconno. It features all the necessary pins for this project and connections so it can be easily soldered to a PCB.
The design also features a 2-pin header for the SWDIO and SWDCLK pins. This is to ensure that the microcontroller can be programmed by the user. The VBUS and D+/D- pins are connected so that the device may exchange data with a computer.

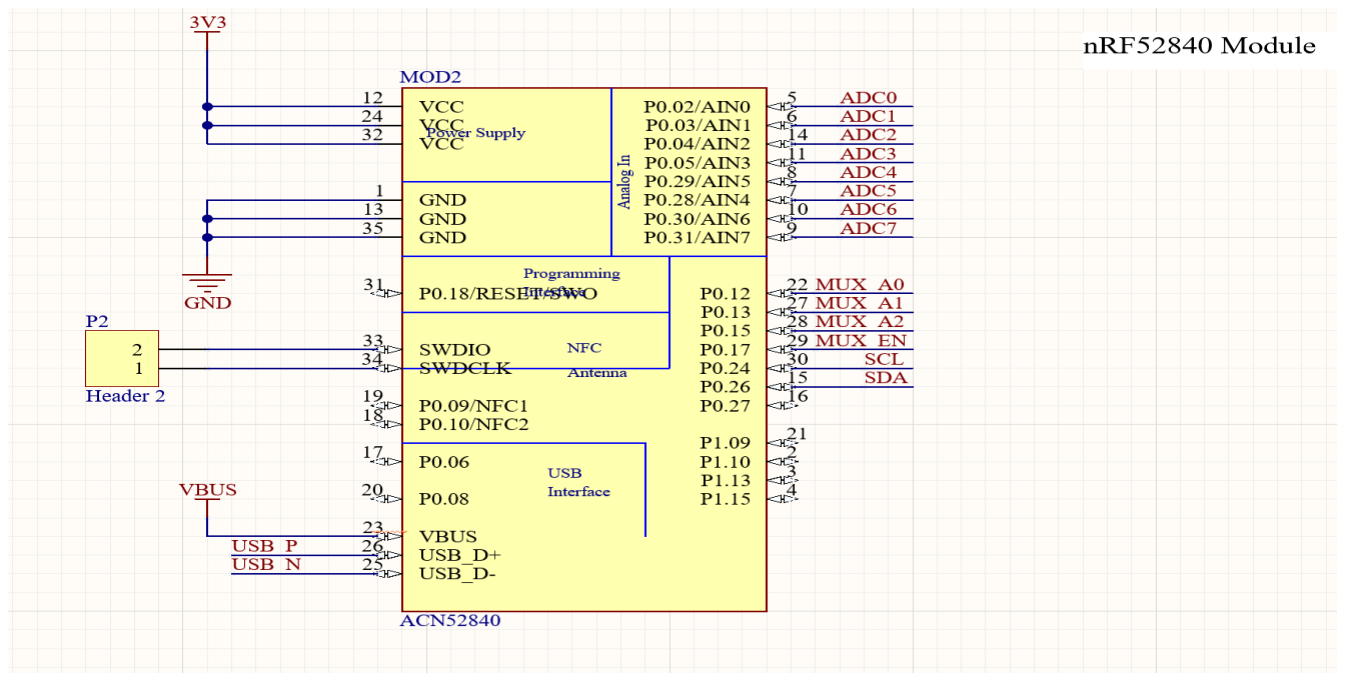
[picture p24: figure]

### 2.1.4 Power Supply

The unit will be powered by a USB-C port. However, most components will require 3.3V, while the USB standard delivers 5V. To convert the 5V to a suitable 3.3V, a buck converter shall be utilized.
The chosen buck converter is the MCP1602-3301. This buck converter has a fixed output voltage of 3.3V.

3

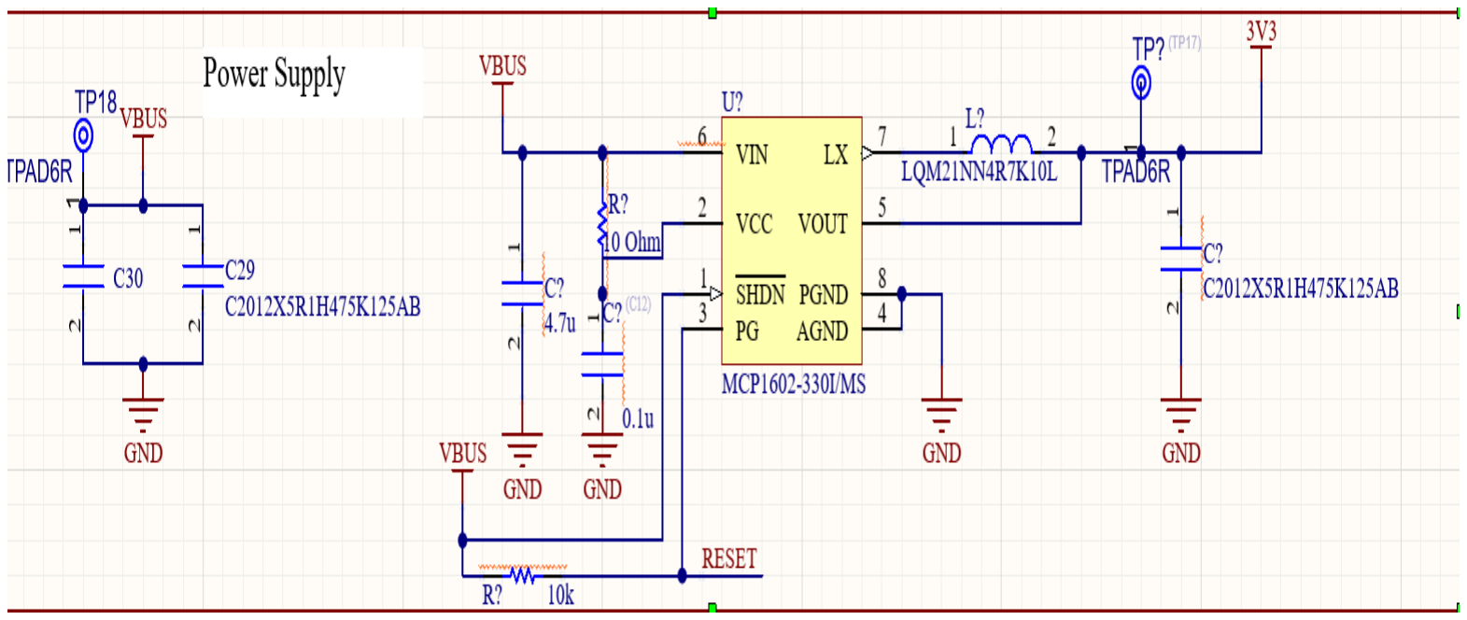
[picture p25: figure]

The only required external components for this chip are the 4.7uF input and output capacitors, followed by the small RC network on the VIN and VCC pins. A 10k pull-up resistor is also used on the PG (power good) pin. This pin indicates if the output voltage is within 94% of regulation. The NOT SHDN (shutdown control) pin (1) is a pin used to enable or disable the converter. A logic high (¿45% of VIN) will enable the device. While an a logic low (¡15% of VIN) will disable the device. This device features two different ground pins, AGND (analog ground) and PGN (power ground). LX is connected directly to the buck inductor. VOUT is the output pin.

### 2.1.5 USB

The product will feature a USB-C connection. This connection is used to supply the product with power, but also to enable data communication between this device and another (desktop pc, laptop etc.). The USB-C port will be wired according to USB 2.0 specifications, meaning the USB connection will supply the device with a voltage of 5V and a maximum current of 500mA.
The USB-C port requires two 5.1k resisot

4

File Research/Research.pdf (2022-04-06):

# Research

Irfaan Bodha

February 2022

## 1 Introduction

This research document shall detail the research and experiments that shall be done in support of the three phase power monitoring project. In order to determine suitable requirements, experiments shall be done on magnetic sensors. The chosen sensors for these experiments are:
- Rogowski Coils
- Hall Effect Sensors
- Magnetoresistive Sensors

An amplifier circuit shall be designed and produced for the Rogowski coil. The procedures and calculations will be detailed in this report. To test the hall effect sensor, a hall effect module shall be connected to an Arduino Uno and the outputs will be read through a PC running an Arduino serial monitor. The magnetoresistive sensors will be mounted to a PCB and will also be read through a PC and Arduino software.

## 2 Rogowski Coils

### 2.1 Theory

Rogowski coils have been used for current measuring since 1912. [1] Traditionally, Rogowski coils have only been considered when other methods were unsuitable. Starting in 1965, the CEGB laboratories at Harrogate began investigating Rogowski coils for use in the power industry and developed the technology to produce high-accuracy and reliable measuring systems using Rogowski coils. [2]

Rogowski coils are toroidal windings placed around the conductor from which they will be measuring the current of. This way, the coil will pick up the electromagnetic field (EMF). The output of the winding is an EMF proportional to the rate of change of current. This is where the Rogowski coil differs from a current transformer, as a current transformer outputs the current that is being measured. The coils are designed to reject external magnetic fields, so that they may provide accurate measurements. The coil can be wound on a rigid former or it can be wound on a flexible former.

In order to monitor the current, the output of the Rogowski Coil has to be integrated. This is because the output of the coil is proportional to the rate of change of current. For this experiment, however, this shall not be necessary, since we are only interested in how sensitive a Rogowski coil is.

The output of a Rogowski coil is very low however, it can be as low as 40 microvolts per amp. [1] For this reason, an amplifier must be used in order to produce a reliable signal.

By choosing correct values for the amplifier, a single coil could theoretically be used to measure an extremely wide range of currents. The coil itself could also be wound more tightly, in order to increase the number of turns and therefore increasing its sensitivity.


Figure 1: Amplifier using a TL074 op amp.

One of the advantageous features of the Rogowski coil is that it is linear, because of this the coil could be used to measure a wide range of currents. Instead of having to change the coil when switching systems, the gain of the amplifier could be adjusted instead.

### 2.2 Circuits

### 2.2.1 TL074 Amplifier

Two proposed circuit will be discussed in this section. The goal of the circuits shall be to amplify the output of the Rogowski coil so that it may be interpreted by a micro controller or observed through an oscilloscope. The output of the Rogowski coils are extremely low, that’s why the signal must be amplified. An op amp amplifier circuit shall be utilized for this. See figure 1 for a schematic of the amplifier using the TL074 op amp. The gain can be tuned by adjusting the value of R4. We can calculate the gain of this simple using formula 1.

GAINnon−inv =

VOutmax − Voutmin

VInMax − VInM in

= 1 +

R5
R4

(1)

### 2.2.2 TL074 Level Shifter

The output of a Rogowski Coil is not suitable for the input of an ADC. The ADC of an Arduino cannot read signals below -0.3V. Therefore, if we wish to observe the output through an Arduino, we will have to implement a level shifter circuit.

With a reference voltage of 2.5V, our signal will swing from that point rather than from 0V. This will prevent our signal from going below 0v, thus making it readable by an Arduino.


Figure 2: Level shifter using a TL074 op amp.

The gain for the level shifter can be calculated using formula 2.

GAIN =

R7
R9

∗

R9 + R8
R6 + R7
IfR9 = R6, then :

GAIN =

R7
R9

(2)

### 2.2.3 OPA2342

A circuit for the Rogowski coil using an OPA2342 shall now be discussed. This op amp features a few improvements over the TL074. Firstly, the op amp is a rail-to-rail amplifier. Unlike the TL074, input signals can swing all the way up to the level of the supply voltage. Secondly, a single supply voltage is sufficient to properly amplify the signal correctly. This makes a level shifter redundant as well, since the single (positive) supply voltage makes it so that the amplified signal stays in the positive range.

See figure 3 for the circuit. The gain for this amplifier can be calculated using the same formula as the gain formula for the TL074, formula 1, by plugging the values for R3 and R2 in R5 and R4 respectively.

### 2.3 Simulations

In this section, the results of the simulations will be discussed. Multiple sweeps have been performed, including temperature sweeps, AC frequency sweeps and resistance sweeps.


Figure 3: Amplifier using OPA2342 op amp.

### 2.3.1 TL074 Simulations

The first simulation will be a resistance sweep on R4. This will be done to simulate a potentiometer, so that the gain may be adjusted on the fly. See figure 4 for the results. As expected, the higher the resistance goes the weaker the signal becomes because of the lowered gain.

Next, a temperature sweep shall be run to monitor the performance of the amplifier circuit through a certain range of temperatures. A sweep running from 0 degrees celsius to 100 degrees celsius has been selected. Notice how much the offset varies once the temperature starts to rise above 70 degrees celsius. See figure 5 for the results.

Lastly, an AC frequency sweep shall be performed. With this sweep we will simulate the frequency response of the circuit and we will be able to see the cut off frequency. See figure 6 for the results.

### 2.3.2 OPA2342 Simulations

In this section we will discuss the simulations performed on the OPA2342 circuits. Just like with the TL074, multiple sweeps were performed to monitor the behaviour of the circuit based on temperature, frequency and resistance.

The first simulation will be the resistance sweep. Here, R2 (3) will be simulated with varying values, to simulate a potentiometer. See figure 7 for the results. Once again, the gain lowers as the resistance increases.


Figure 4: TL074 resistance sweep

Figure 5: TL074 temperature sweep


Figure 6: TL074 frequency sweep

Figure 7: OPA2342 Resistance sweep.


Figure 8: OPA2342 Temperature sweep

Next up is the temperature sweep. A temperature range of 0 degrees Celsius up to 100 degrees Celsius has been selected. See figure 8 for the results. Note how temperature affects this circuit much less than the TL074 circuit. In fact, it appears that temperature barely affects the circuit at all.

Finally, we have the frequency sweep. The sweep ran from 50Hz up to 100KHz. We can see in figure 9 that the cut off frequency is at 10KHz.


Figure 9: OPA2342 frequency sweep

## 3 Hall Effect Sensors

### 3.1 Theory

### 3.1.1 Background

The hall effect sensor is named after American physicist Edwin Hall. Hall discovered that objects can be moved by electricity and magnetism. Hall effect sensors used that principle to convert magnetically encoded information into electrical signals.

Hall effect sensors have a vast range of applications, including several uses in the automotive industry such as position sensing, speed and distance sensing etc.

### 3.1.2 How do Hall effect sensors work?

When a current flows through any material, the electrons in the current move in a straight line. The electricity creates its own magnetic field. If this electrically charged material is placed between the poles of a permanent magnet, the electrons will move with a curved path instead. This is because their own magnetic fields react to the magnet’s magnetic field. As a result of this, more electrons will be present at one side of the material than the other. Because of this a potential difference, voltage, appears across the material. [3]

Hall effect sensors will measure the changing voltage across this material. With this method, the sensor can detect that is in a magnetic field.

Hall effect sensors are activated by an external magnetic field. The two most important characteristics of a magnetic field are flux density (B) and polarity (north and south).

The output of a Hall effect sensor is the function of the magnetic field density around the sensor. When the external magnetic flux density around the sensor exceeds a certain threshold, the sensor will output a voltage called the Hall voltage, Vh.[4]

### 3.1.3 Current-sensing techniques

Hall effect sensors are usually utilized to detect proximity, position or speed of mechanical targets. They can, however, also be used as current sensors. The way this is achieved is by measuring the magnetic field that is generated by the current.

In theory, to create a current sensor a hall effect sensor could be placed close to a conductor that is carrying a current. The sensor has to be placed in such a way that the magnetic flux lines can be detected, see figure [x].


Assuming that there is only empty space surrounding the conductor and the conductor has a circular cross-section, the magnitude of the magnetic field can be calculated by the following equation:

B =

µ0I
2πr

(3)

R in this equation is the distance to the center of the conductor in meters.

While this would be an ideal setup, in reality this introduces several problems. Firstly, the generated magnetic field will not be substantial. For example, a 10 amp current will only generate about 2 Gauss at a distance of 1 cm.

4π ∗ 10⁻⁷ ∗ 10
2π ∗ 0.01
= 0.0002T or 2 Gauss | (4)

By this logic, the sensor will be influenced by external fields. One example of a field that could influence the
readings would be the magnetic field of Earth. Earth has a magnetic field of about 1 | 2Gauss. The generated
error would be 2.5 amps. From this we could draw the conclusion that in this configuration the hall effect sensor would only be suitable for measuring extremely large currents. If this would be applied for systems with less current, the measuring error would relatively be much higher.

2π ∗ 0.01 ∗ 0.00005
4π ∗ 10⁻⁷
= 2.5A | (5)

The second challenge would be the difficulty of correctly placing the sensor. To make the sensor effective, it is very important to place the hall effect sensor in the correct spot.

Thirdly, the calculations above assume an infinitely long and straight cable. In reality, however, cables are not infinitely long and there is a chance of the cable flexing and bending. The flexing and bending will have a major impact on the sensor’s sensitivity.

## 4 Magnetoresistive sensors

### 4.1 Theory

Magnetoresistive sensors (MR sensors) are linear magnetic field transducers. A MR sensor uses the fact that the electrical resistance in a thin magnetic film alloy is changed through an external magnetic field. Materials such as iron and nickel are commonly used for this alloy. MR sensors are very small and highly efficient, using very little current to operate. [5] An MR sensor can be used for multiple applications, such as:
- Angle measurement
- Magnetic field sensing
- Used as switches
- Current measurements

A simply way to explain the working of the sensors would be as follows: When the sensor comes into contact with a magnetic field, the electrical resistance changes. This also makes it possible to detect at what angle the external object is located. The magnetic field also makes it possible to determine the distance.

Technology has advanced to the point where researchers were able to create nanostructured multilayer devices with succesively larger giant magnetoresistance (GMR) and tunneling magnetoresistance (TMR) effects. Together with anisotropic magnetoreistance (AMR), these three types of sensors are currently in use.

A way to calculate the maximum obtainable signal from the sensor would be as follows:

MR% = Rmax − Rmin

Rmin

(6)

As mentioned earlier, the three types of MR sensors that will be discussed in this research are:
- AMR Sensors
- GMR Sensors
- TMR Sensors

### 4.2 Anisotropic magnetoresistance

AMR, or anisotropic magnetoresistance, sensors depend on the angle between the electric current and the magnetization direction. The AMR effect is a change in the paths of the electrons. The magnetic field distorts these paths. The change is maximum when the magnetic field is parallel to the sensor.

The resistance of the material of the sensor can be given by the following formula:

R = R0 + δR | (7)

## References

[1] V. Fehlberg, “How rogowski coils work.”
[2] D. Ward, “Measurement of current using rogowski coils.”
[3] R. Ltd., “Everything you need to know about hall effect sensors.” [Online]. Available: https://ie.rs-online.com/web/generalDisplay.html?id=ideas-and-advice/hall-effect-sensors-guide
[4] E. | tutorial, | “Hall | effect | sensor.” | [Online]. | Available: | https://www.electronics-
tutorials.ws/electromagnetism/hall-effect.html

[5] S. C. P P Freitas, R Ferreira and F. Cardoso, “Magnetoresistive sensors,” 2007.

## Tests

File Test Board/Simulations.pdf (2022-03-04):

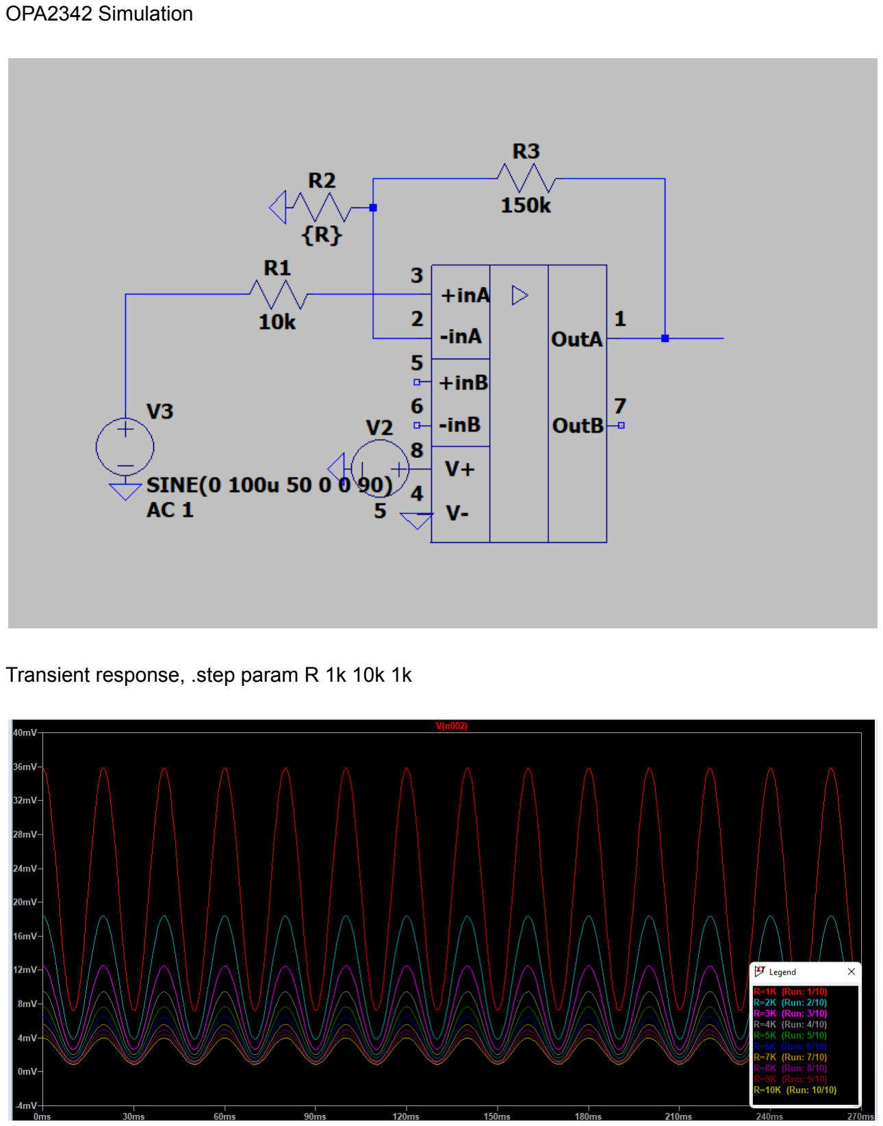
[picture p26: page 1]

OPA2342 Simulation

Transient response, .step param R 1k 10k 1k

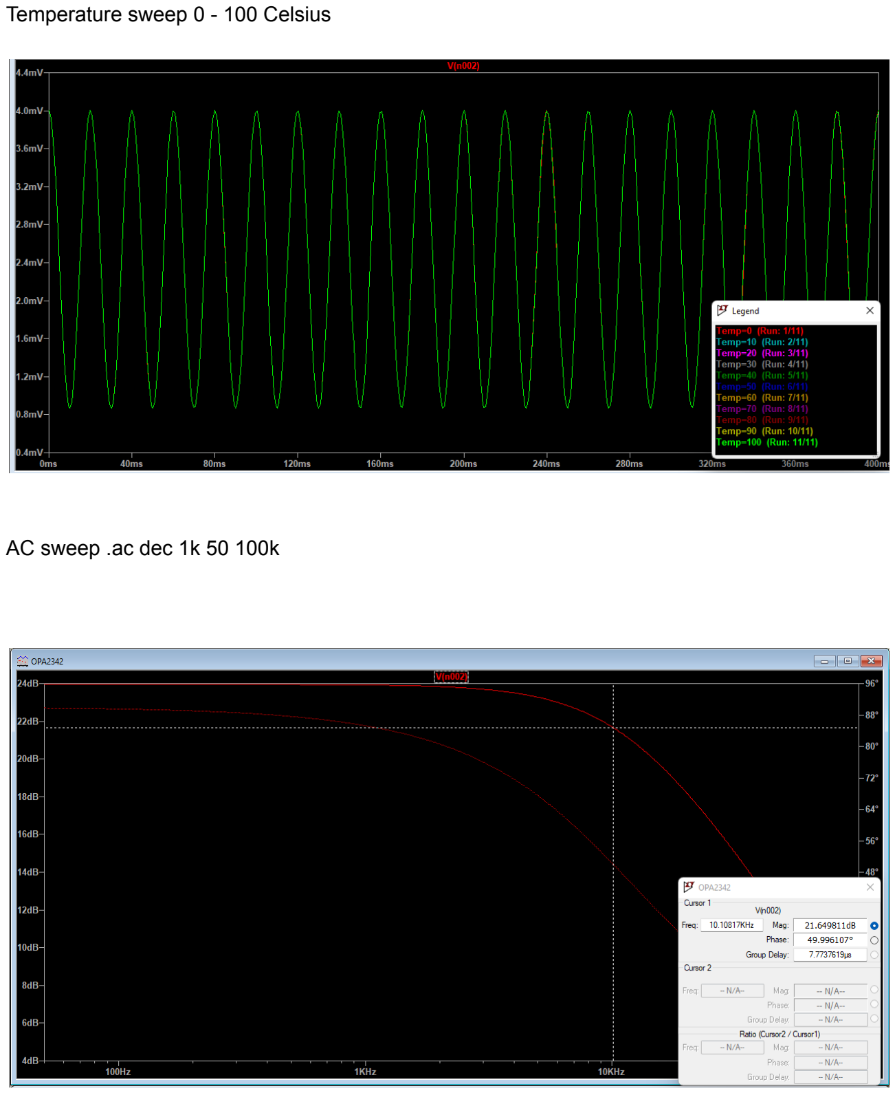
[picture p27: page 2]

Temperature sweep 0 - 100 Celsius

AC sweep .ac dec 1k 50 100k

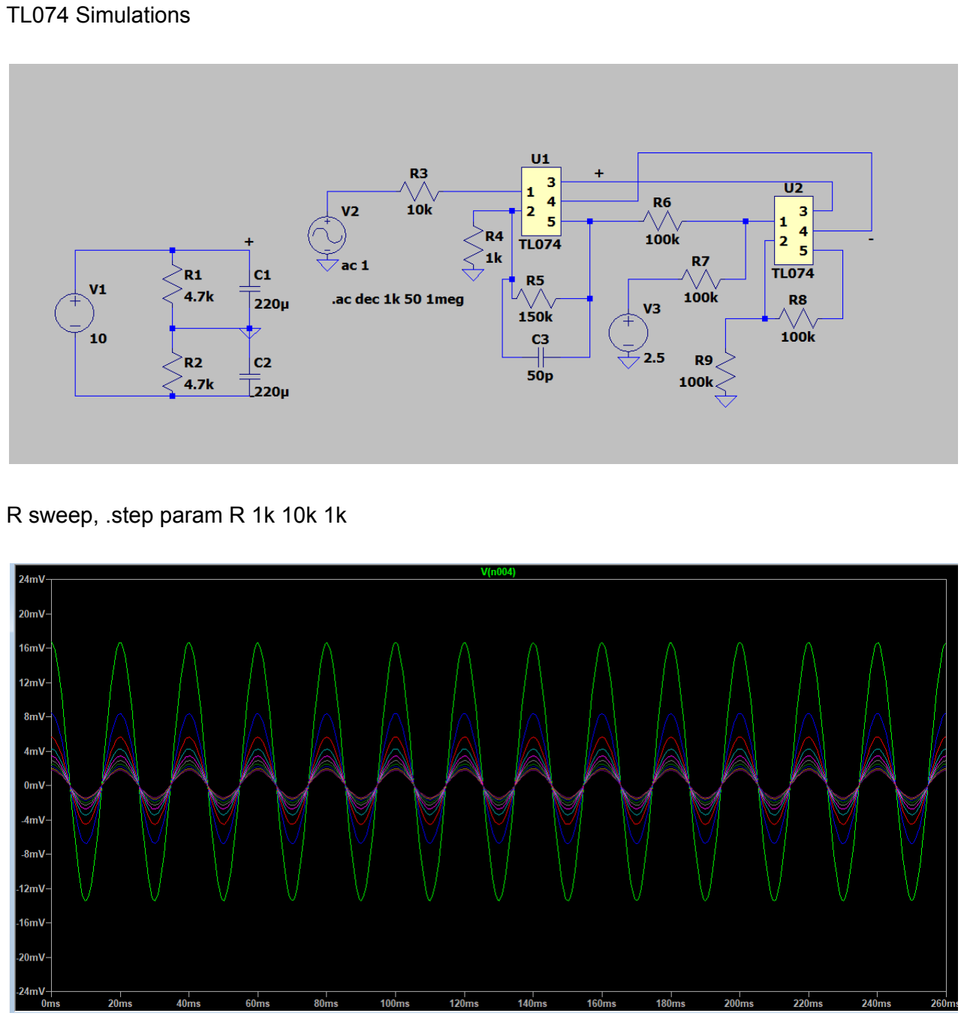
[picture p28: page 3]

TL074 Simulations

R sweep, .step param R 1k 10k 1k

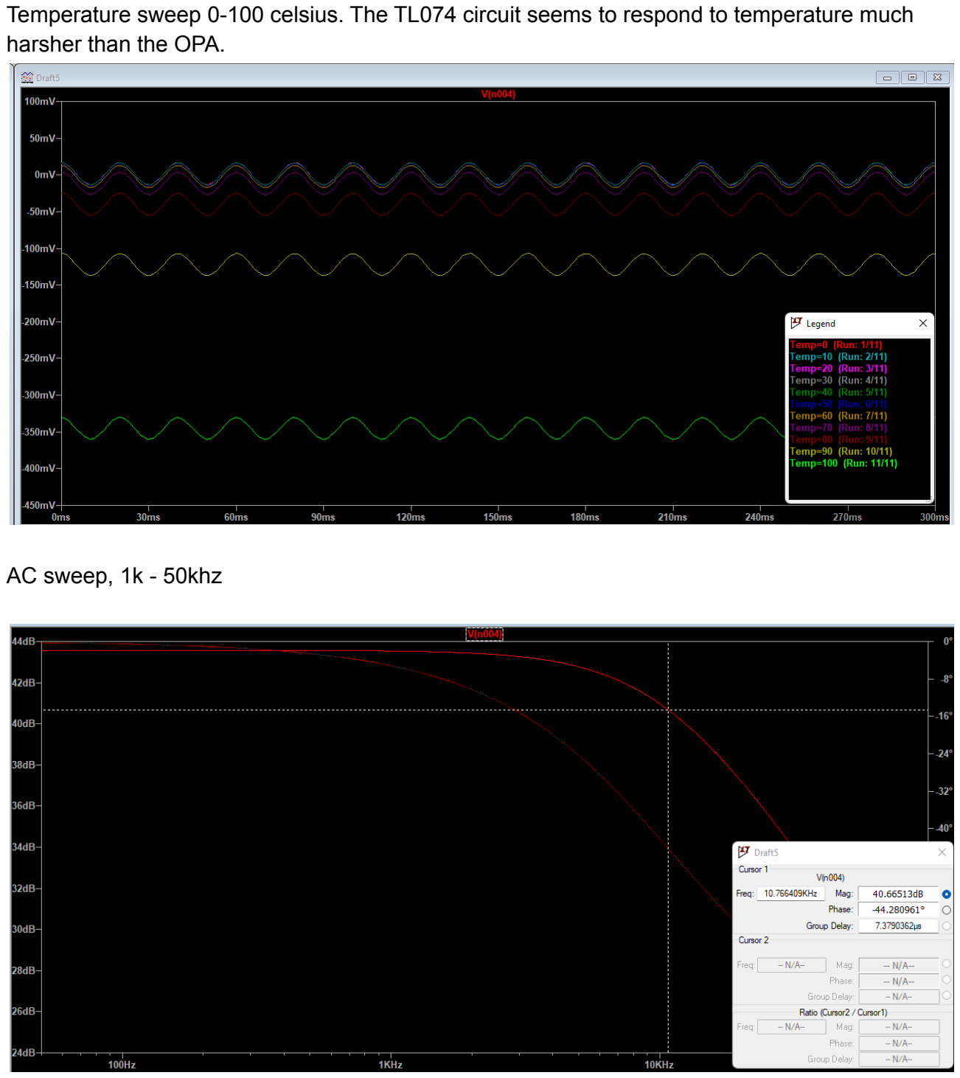
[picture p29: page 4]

Temperature sweep 0-100 celsius. The TL074 circuit seems to respond to temperature much harsher than the OPA.

AC sweep, 1k - 50khz

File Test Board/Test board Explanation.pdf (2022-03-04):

Test board

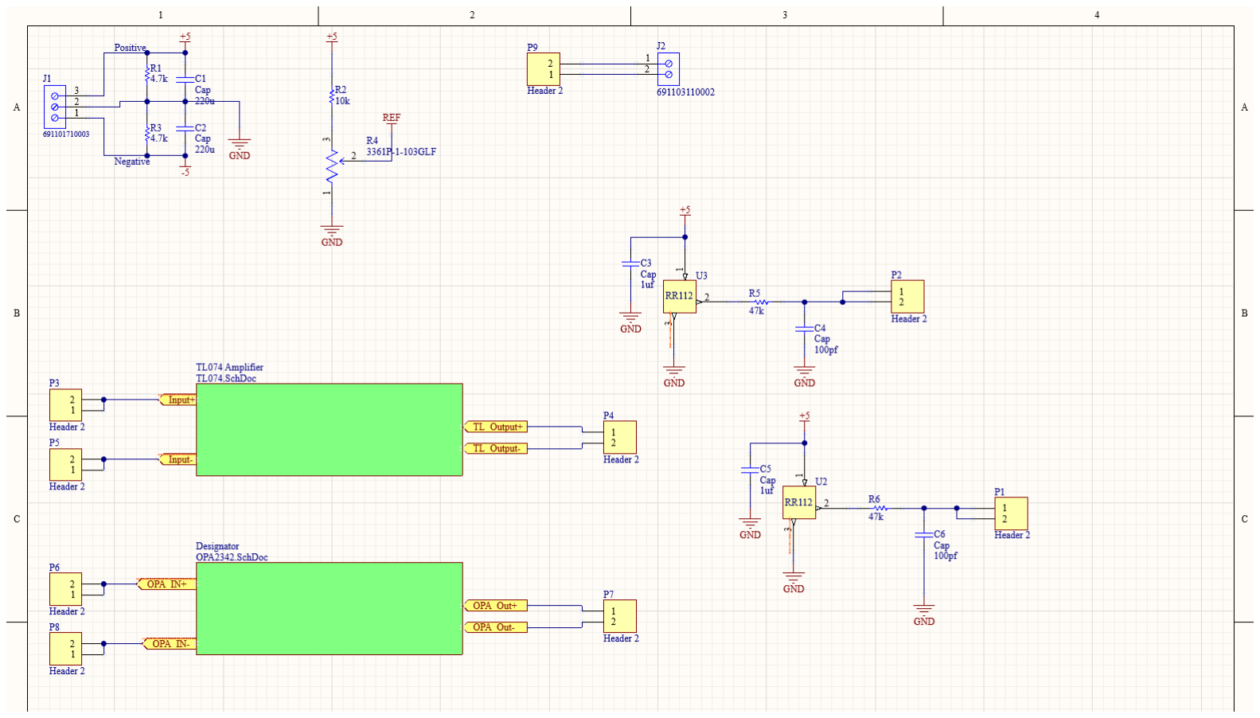
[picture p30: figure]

Above is the complete schematic of the circuit. It features a voltage divider to generate +5V and -5V supplies. It also features another voltage divider with a potentiometer for the purpose of creating a reference voltage for the TL074 level shifter, which shall be discussed more in depth later.

This schematic also features two TMR sensors, the RR112’s. These only require a low pass
filter before being read by an ADC, this filter has an Fc of: | .

1
2*pi*47k*333p = 10. 2KHz

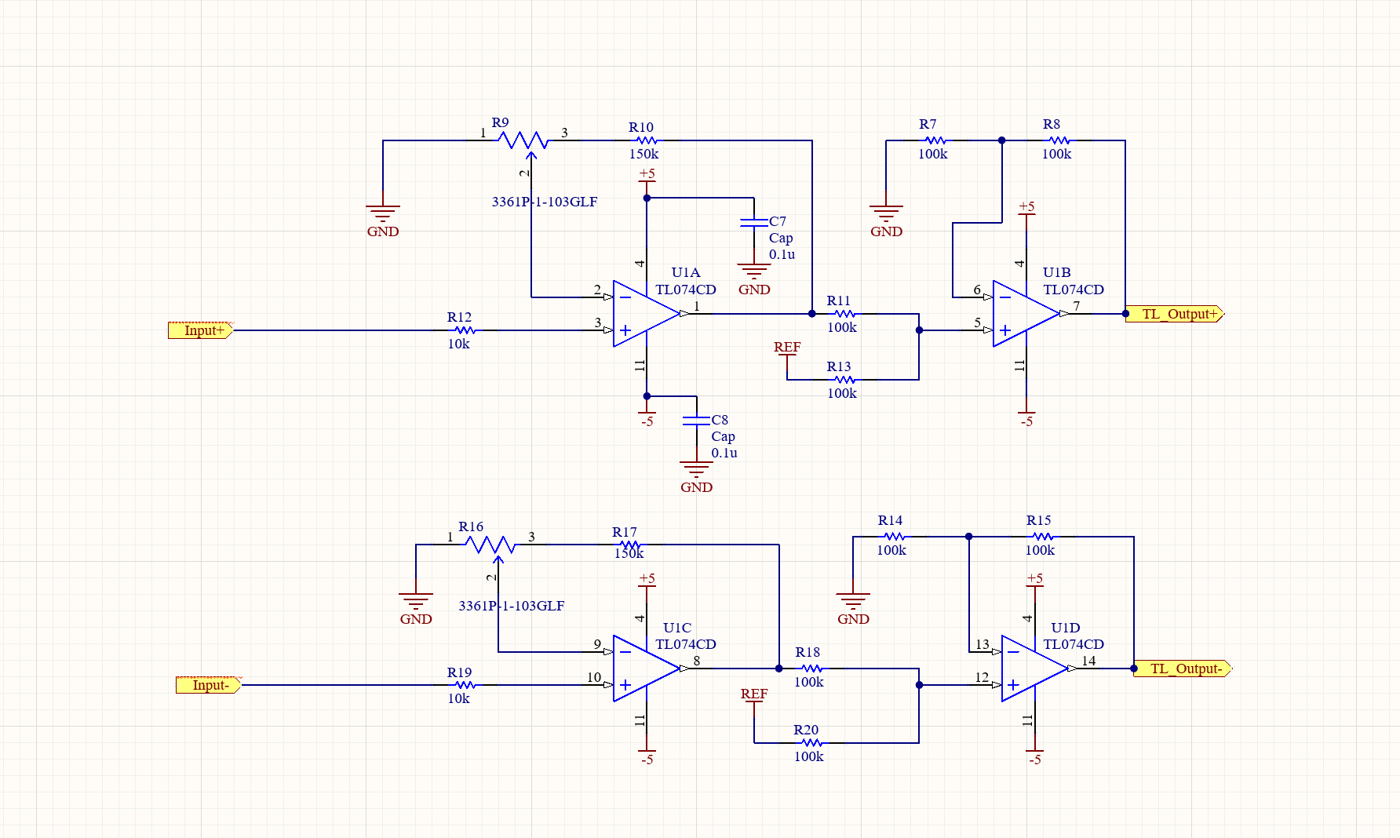
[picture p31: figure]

This is the TL074 circuit. The TL074 requires a positive and negative voltage for the supply, if only a positive voltage is supplied it will cause some offset issues. It features 4 opamps, two of which are used as amplifiers while the other two are used as level shifters. The gain of the amplifiers are determined by the 150K resistors and the potentiometers.
The level shifters have a gain of 1, since they’re only being used to shift the signal up into the positive, so it can be read out by an ADC.

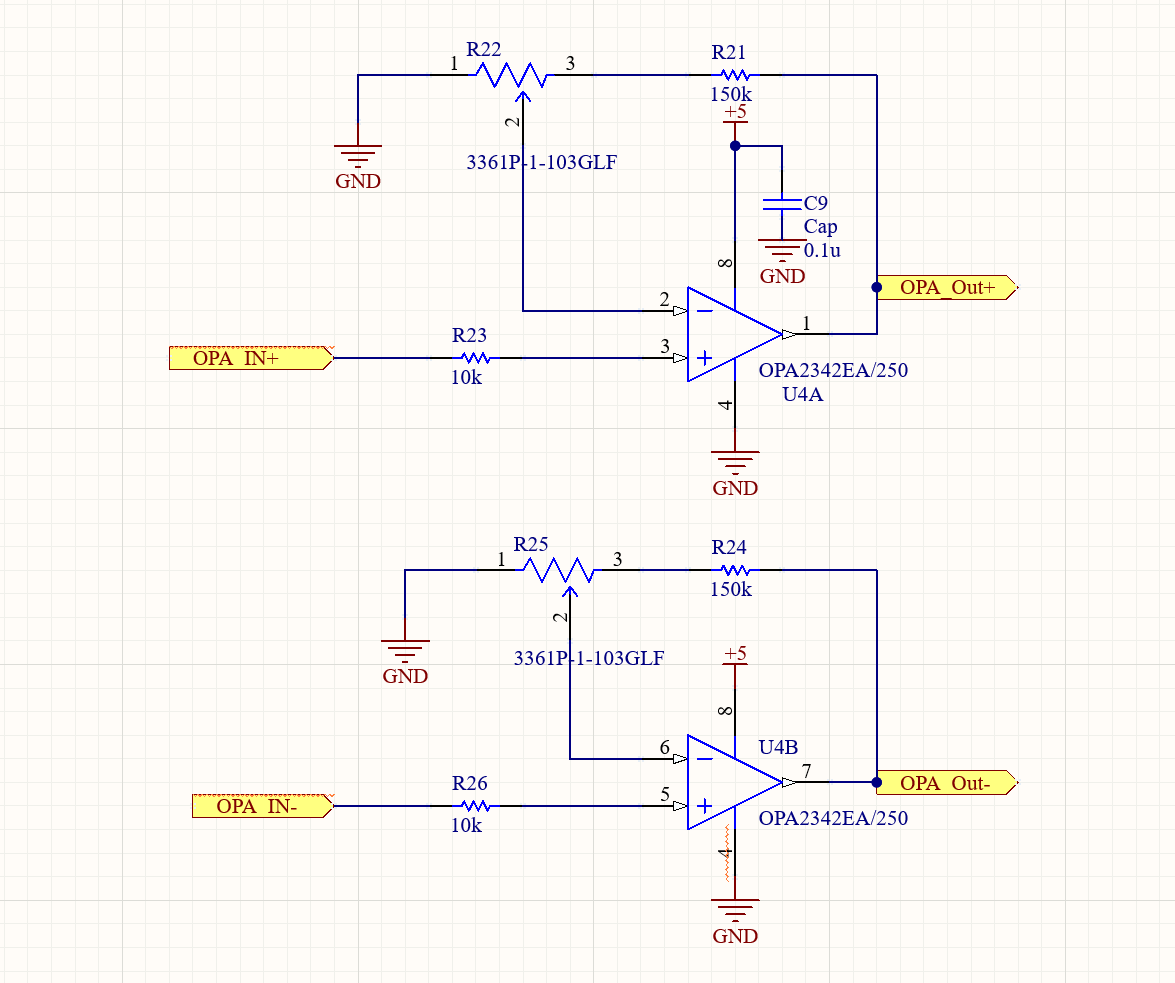
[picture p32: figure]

The OPA2342 circuit is simple compared to the TL074 one. It features a single supply voltage and no level shifters. Level shifters are not necessary when utilizing this opamp. Once again the gain of this amplifier is determined by the 150K resistors and the potentiometer.

Both the circuits will output their signals to headers, to which a microcontroller can be easily connected to.

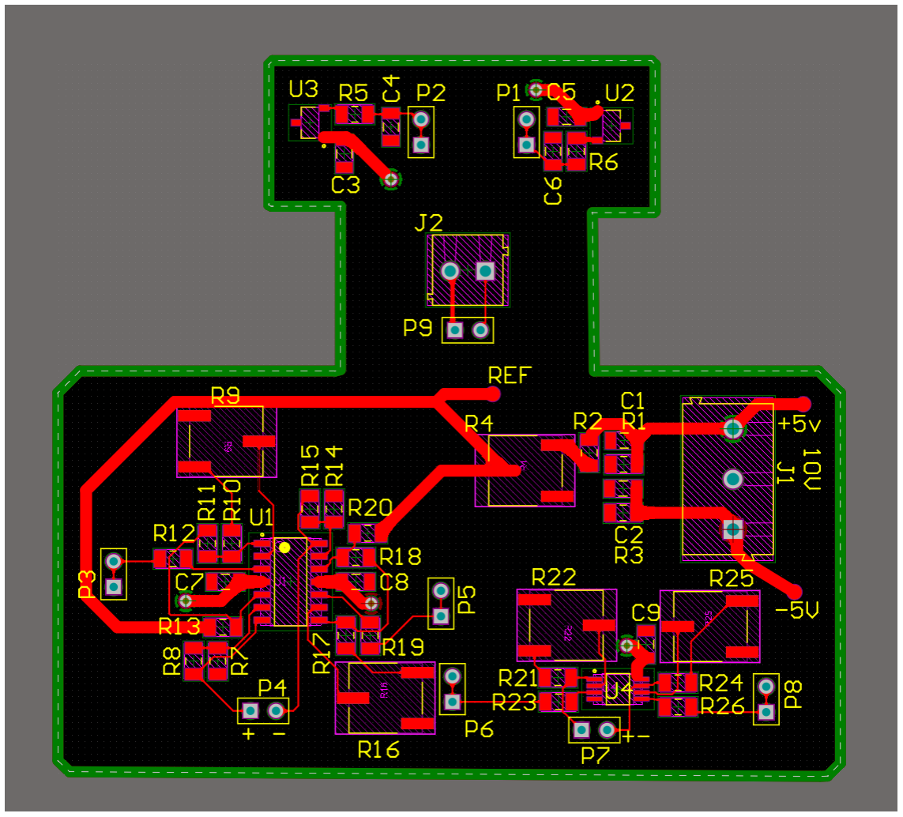
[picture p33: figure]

The two TMR sensors are placed at the top, with a screw terminal slightly below them to allow for Rogowski coil connections. With headers an amplifier can be chosen, the goal of this is so that the outputs of both amplifiers can be compared to each other.

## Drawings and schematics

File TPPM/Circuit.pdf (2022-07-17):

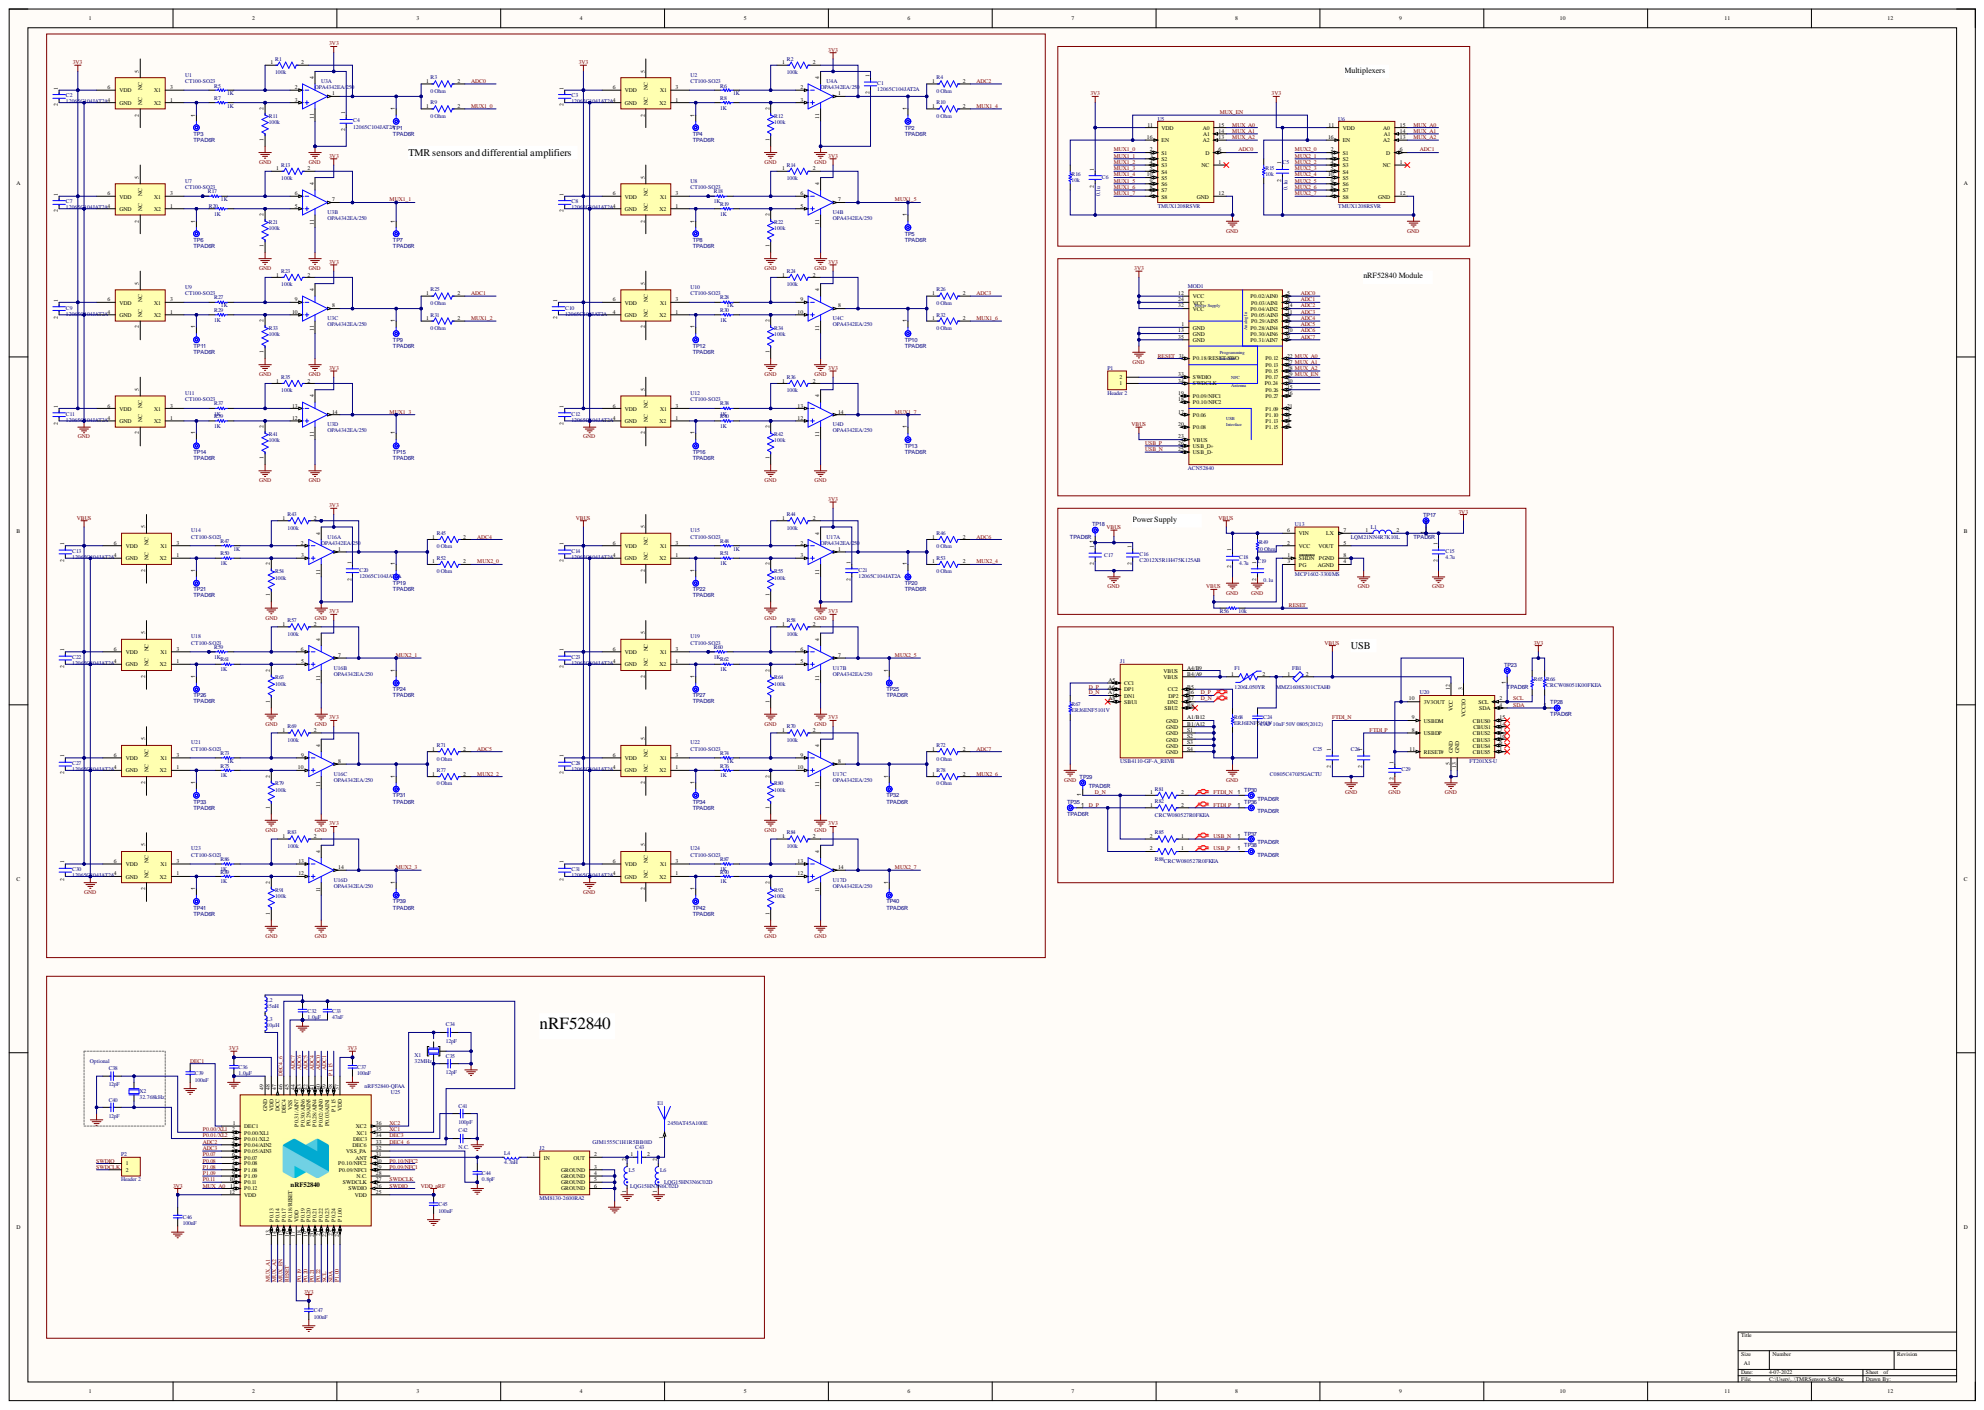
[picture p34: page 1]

TMR sensors and differen

faceNFC Antenna | M U X_A 1 M U X_A 2

Powe r Supply | P 1 7 3V

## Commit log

2022-02-23 Schematic for the PCB containing MGR sensors and Rogowski coils.
    [Test_Board_Sch.SchDoc]
2022-03-04 PCB for testing. Pending review and should be ready for manufacturing soon. Added: - Schematics - PCB - Explanation of circuits - Simulations of said circuits
    [OPA2342.SchDoc, TL074.SchDoc, TestBoard.PcbDoc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]
2022-03-09 This PCB has been submitted for manufacturing.
    [OPA2342.SchDoc, TL074.SchDoc, TestBoard.PcbDoc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]
2022-04-06 Added PCB project file
    [TestBoard.PcbDoc, Test_Board.PrjPcb]
2022-04-06 Altium files of the TPPM
    [Power_Monitor.PrjPcb, TMRSensors.SchDoc]
2022-07-17 Final PCB files
    [3PhaseMeter.SchDoc, Power_Monitor.PrjPcb]
